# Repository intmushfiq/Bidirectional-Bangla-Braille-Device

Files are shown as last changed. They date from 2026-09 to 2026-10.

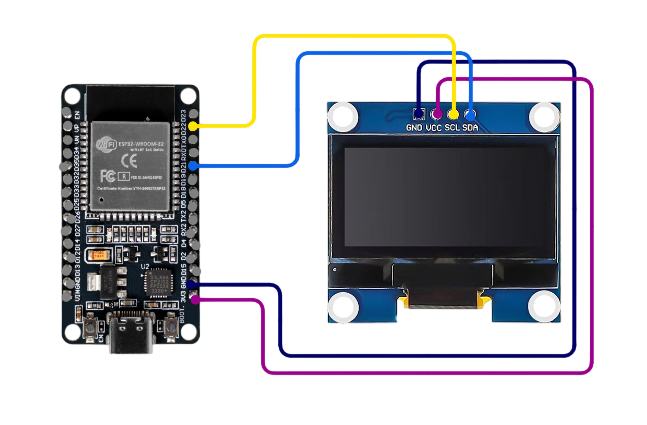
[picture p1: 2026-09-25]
Schematic/OLED_Schematic.png

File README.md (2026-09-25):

# Bidirectional Bangla Braille Translation System

An ESP32-based assistive device that translates **in both directions between six-dot Braille and Bangla text**.

- **WRITE mode (Braille → Bangla):** a blind user types Braille on a six-key keypad. The device shows the Bangla text on an OLED display and speaks each letter through a speaker.
- **READ mode (Bangla → Braille):** a sighted user types Bangla on a web page hosted by the ESP32. The device raises the Braille pattern one letter at a time on a refreshable cell of six solenoids.

EEE 416 (Microprocessor and Embedded Systems Laboratory), Jan 2026 — Section C2, Group 04
Department of EEE, Bangladesh University of Engineering and Technology (BUET)

>  Demo video: *add YouTube link*

---

## Team

| Name | Student ID |
|---|---|
| Mushfiqur Rahman | 2106181 |
| Chayan Paul | 2106182 |
| Shamin Yeaser | 2106183 |
| Kayes Sami Malitha | 2106184 |

---

## Credits and references

- **Audio clips:** letter recordings from [Bengali-Alphabet](https://github.com/lifeparticle/Bengali-Alphabet) by Mahbub Zaman, used under the MIT License. See `audio/LICENSE`.
- **Braille chart:** *World Braille Usage*, 3rd ed., Perkins, ICEB and National Library Service for the Blind and Physically Handicapped, Library of Congress, 2013, "Bangladesh," pp. 9–10.
- **Braille rules:** M. S. Rahman, M. M. Rahman and M. Kaykobad, "Bangla Braille Adaptation," in *Technical Challenges and Design Issues in Bangla Language Processing*, IGI Global, 2013.
- **Libraries:** [BanglaText](https://github.com/mamunul/BanglaText) by Mamunul Mazid · [U8g2](https://github.com/olikraus/u8g2) by Oli Kraus · [DFRobotDFPlayerMini](https://github.com/DFRobot/DFRobotDFPlayerMini) by DFRobot

---

## License

This project is released under the [MIT License](LICENSE). Third-party audio clips and libraries keep their own licenses.

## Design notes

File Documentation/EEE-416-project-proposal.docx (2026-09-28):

Bangladesh University of Engineering and Technology

Department of Electrical and Electronic Engineering

EEE 416 (January 2026)

Microprocessor and Embedded Systems Laboratory

Project Proposal

Section: | C2
Group No: | 04
Student ID(s): | 2106181,2106182,2106183,2106184
Section Teachers: | Tanushri Medha Kundu, Abrar Assaeem Fuad
Project Title: | Design and Implementation of a Bi-directional Bangla Braille Translation Device

# 1 Abstract

This project aims to build a bi-directional Braille learning device that helps visually impaired people read and write in Braille in Bangla. In reading mode, Bangla text is converted into the corresponding Braille pattern, going letter by letter, raising six tactile push-pull solenoids. In writing mode, there is a separate cell in which the user enters a letter using six latching push buttons to spell a word, which is later displayed on an OLED display.

# 2 Background

Braille is the primary means for reading and writing for visually impaired people. However, learning materials in Bangla Braille are scarce and mostly imported, which makes them expensive. Our project aims to build an affordable, low-powered device that allows the user to both read any text file uploaded to the device in real time and also use it as a “Braille Typewriter” to type any word or sentence. This gives learners a self-directed way to practice their reading and writing skills from memory, and can be extended into classrooms and homes where dedicated Braille instructors are not available.

# 3 Complexity Analysis

Our project handles multi levels of complexity which includes-

1. Embedded Hardware Integration: Interfacing the ESP32 with the OLED display, six latching push buttons, speaker module, and Wi-Fi communication.
2. Web-Based File Management: Hosting a web server on the ESP32 to receive text files from a browser and storing them in the LittleFS file system.
3. Braille Translation: Implementing efficient lookup tables to convert Bangla characters into Braille patterns (Reading Mode) and Braille patterns into Bangla characters (Writing Mode).
4. Bangla Text Composition: Processing consonants and vowel signs (কার) to determine the correct character combinations before display.
5. Custom Bangla Rendering: Designing and storing custom bitmap glyphs for Bangla characters since the OLED and U8g2 graphics library do not provide native Bangla font support.
6. Firmware Development: Developing embedded firmware to coordinate hardware control, Braille decoding, file handling, display rendering, and audio feedback in real time.
7. Memory Optimization: Efficiently managing flash memory for firmware, lookup tables, bitmap glyphs, and uploaded text files while minimizing RAM usage during execution.

KPA mapping (the relevant ones from the course outline):

Knowledge Attribute | Application in the Project
K5: Knowledge that supports engineering design in a practice area | The project applies engineering design principles to develop a portable Bangla Braille reading and writing device. The system design includes selecting appropriate hardware components (microcontroller, six tactile Braille buttons, audio output module, and storage), designing separate Reading and Writing modes, implementing Bangla Braille encoding and decoding, and developing a user-friendly interface suitable for visually impaired users.
K6: Knowledge of engineering practice (technology) in the practice areas in the engineering discipline | The project demonstrates engineering practice through the implementation of embedded-system technologies, including microcontroller programming, GPIO interfacing for six tactile button outputs and latching button inputs, file handling for reading Bangla text, Braille pattern generation, Braille input recognition, audio feedback, firmware development (writing the codes in C), and integration of hardware and software into a functional assistive device.
K7: Comprehension of the role of engineering in society and identified issues in engineering practice including ethics, public safety, economic, social, cultural, environmental, and sustainability considerations | The proposed device promotes inclusive education by enabling visually impaired users to read and write in our mother tongue, Bangla. By utilizing low-cost embedded hardware and focusing on the Bangla language, the system improves accessibility, supports independent learning, and demonstrates the role of engineering in developing socially responsible technology.

# 4 Technical Requirements

1.Microcontroller | A programmable microcontroller ( ESP32 ) capable of handling GPIO operations, memory management, and peripheral interfacing.
2. Braille Interface | One cell built of 6 push-pull solenoids for reading mode and another cell with 6 latching buttons for braille writing mode, along with normal push buttons for navigation (read the next letter or take the reading of the next input in writing mode) and mode selection (reading or writing).
4, Speaker | One speaker for audio feedback of the letter just given as input so that the user can confirm if they type correctly.
5. OLED display | One OLED display to show the word typed for others
6. MOSFETs | We need six MOSFETs to drive the output tactile solenoids as they draw large currents, and connecting the solenoids directly to the ESP32 will cause damage.
3. Power Supply | We shall use an adapter that connects to the grid directly to turn on the device and use it as the main power source driving the tactile buttons.

# 5 Proposed Methodology

Reading Mode:

Setup phase (Once per text file)

1. The user connects phone/laptop to the ESP32's WiFi network and opens its IP address in a browser.
2. The ESP32 runs a small web server that serves a simple upload page.
3. The user selects and uploads the Bangla .txt file through that page.
4. The ESP32 receives the raw bytes over WiFi and writes them, unchanged, into a file in its own flash storage using the library LittleFS.h.

Reading loop (runs continuously while displaying)

5. The program opens that saved file and keeps a File object that automatically tracks which byte to read next.

6. On each step, it reads bytes starting at the current position. Since Bengali code points are 3 bytes in UTF-8, it reads 1 first byte to detect a 3-byte sequence, then reads the other 2, and combines all 3 into a single Unicode code point.

7. That code point is looked up in the pre-saved Braille mapping table to get a 6-bit dot pattern.

8. The ESP32 drives the six actuators according to that pattern, raising the correct dots.

9. It waits for the user's "next" button press.

10. On the next press, it loops back to step 6 and reads the next character — continuing from exactly where the file cursor left off, with nothing about the previous character kept in memory.

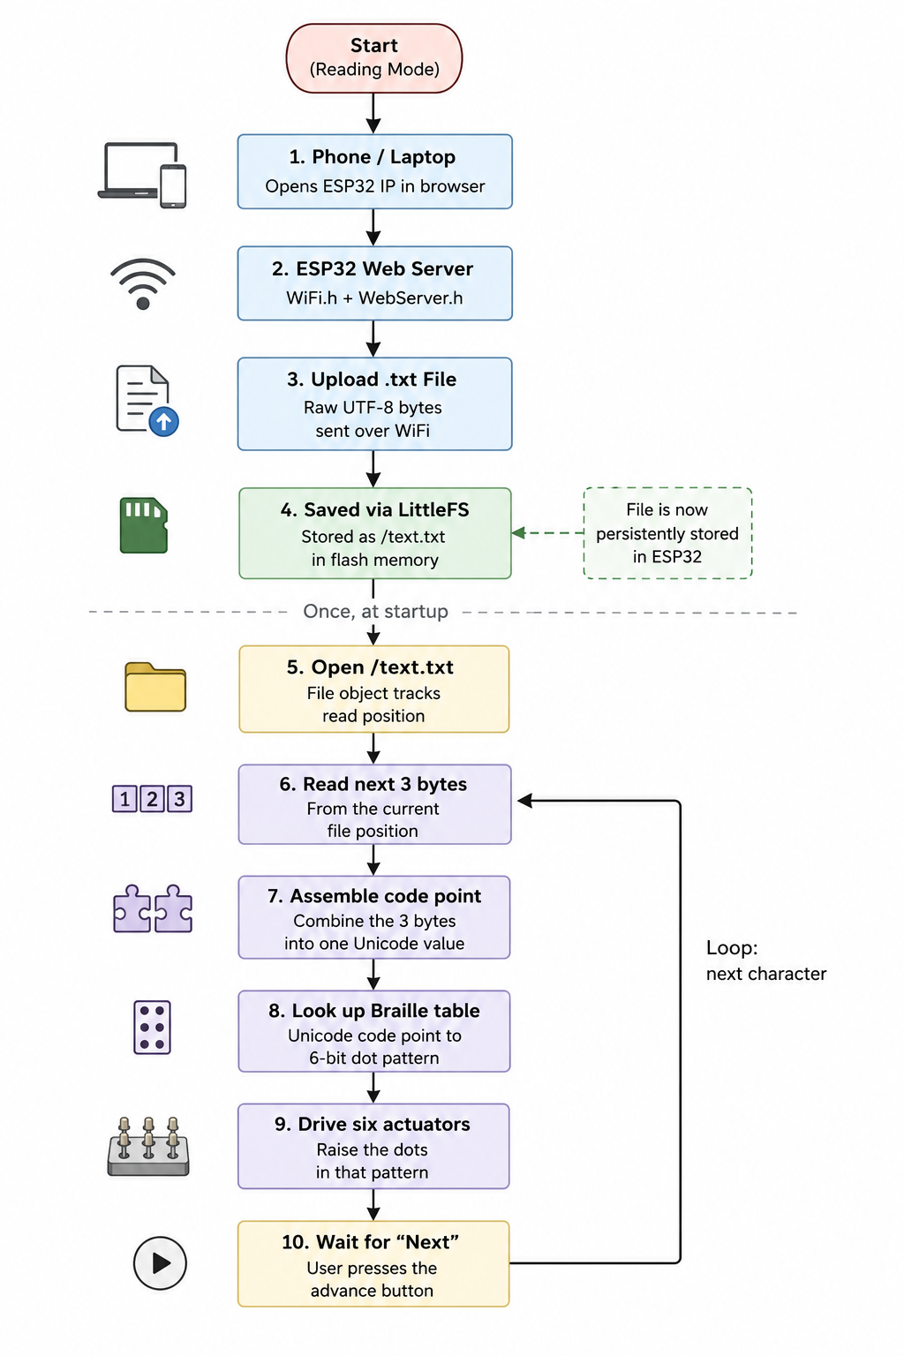
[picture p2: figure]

Fig: Reading Mode

Writing Mode:

There are two main concerns regarding the writing mode,

1. The OLED display does not provide native support for rendering Bangla Unicode characters. Although the U8g2 graphics library manages communication with the OLED and provides drawing functions, it does not include Bangla fonts by default. Therefore, custom bitmap glyphs must be created for each Bangla character (and required character combinations with vowel signs) so that the microcontroller can accurately render the intended text on the display. For simplicity we will map the bitmaps of each individual letter and their vowel attached form in the memory (rather than “building” the “kaar” attached form of that letter from the input) so the whole thing can be used as a look up table.

2. Since Bangla language have “kaar” and the Braille system does not have a separate encoding for “kaar” and assumes that if a vowel appears after consonant it has to be a “kaar” attached to it, we will need to logically implement it using “lookahead buffer” approach before displaying it on OLED. It takes one input and then waits for the next one. If it is a standalone vowel, it directly shows the output but if it is a consonant and the next letter is vowel it combines them to display the text format with “kaar” attached.

The pipeline for the writing mode is as below-

1) The user types a single letter using the 6 latching push buttons.
2) The device waits for the Enter push button
3) It reads the states of the six push buttons and generates the corresponding 6-bit Braille pattern.
4) Searches the Braille lookup table (six bit pattern to direct OLED display glyph Bitmap) to identify the corresponding Bangla character.
5) Determines whether the recognized character is a consonant. If No, retrieve its display glyph from the glyph lookup table and proceed to Step 10.

If Yes, continue to Step 6.

6) Peeks at the next Braille input without permanently processing it.
7) Determines whether the next character is a vowel sign (কার). If Yes, combine the consonant and vowel sign into a composed character (e.g., ক + ি → কি) and retrieve the corresponding glyph from the lookup table. If No, retrieve the glyph corresponding to the consonant alone.
8) Updates the text buffer with the final character or composed character.
9) Generates the corresponding audio output and announces the recognized character through the speaker.
10) Renders the selected glyph on the OLED using the U8g2 graphics library.
11) Repeats the process for the next Braille input until the writing session is complete.

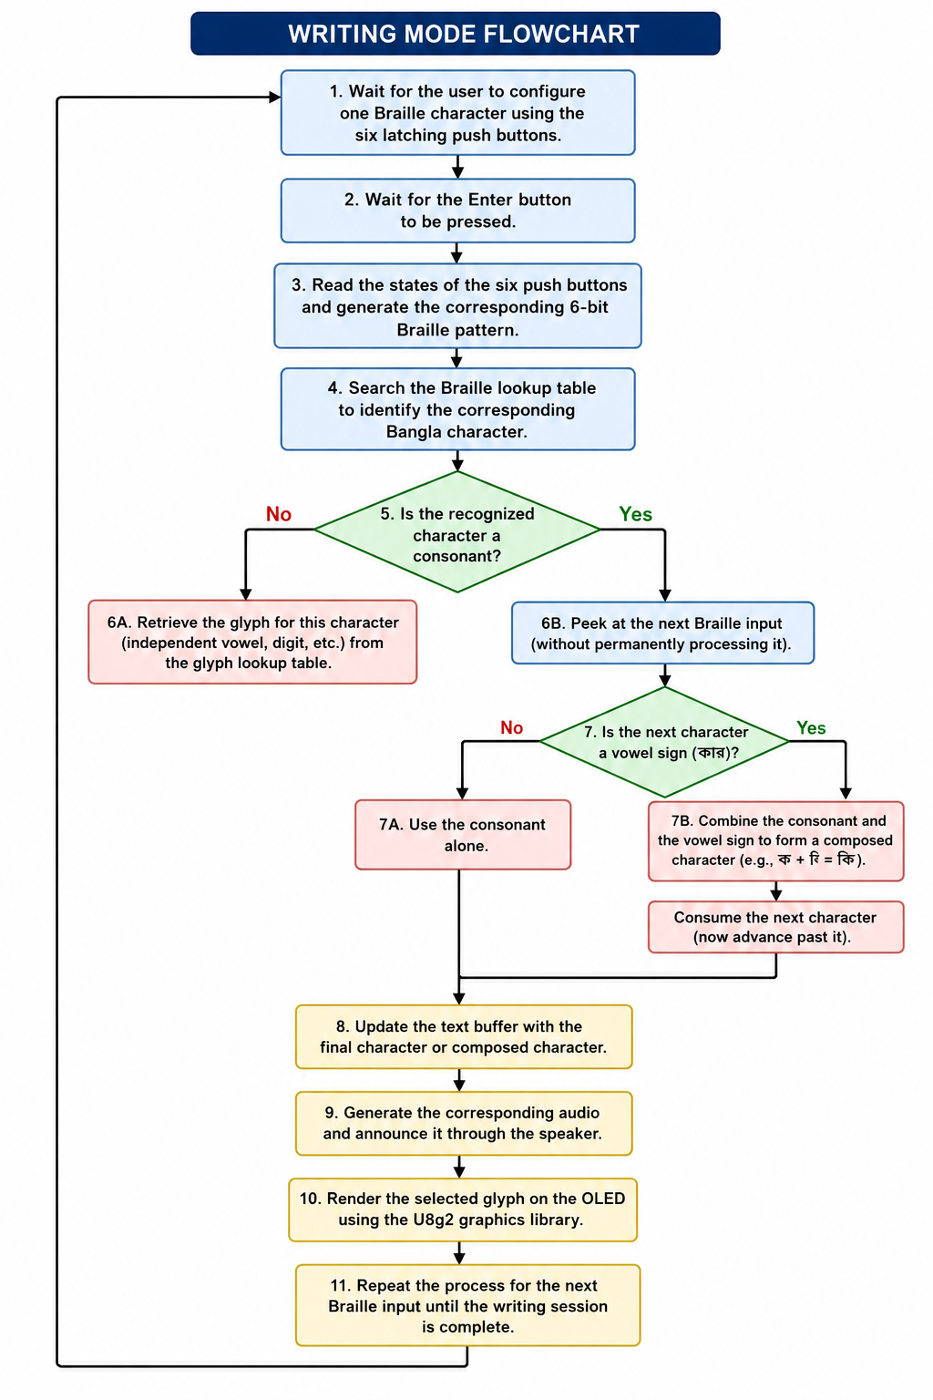
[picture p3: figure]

Fig: Writing mode pipeline

# 6 References

1. https://www.sciencebuddies.org/science-fair-projects/project-ideas/Elec_p109/electricity-electronics/refreshable-braille-display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
2. [1] M. S. Rahman, M. M. Rahman, and M. Kaykobad, "Bangla Braille Adaptation," in Technical Challenges and Design Issues in Bangla Language Processing, M. A. Karim, M. Kaykobad, and M. Murshed, Eds. Hershey, PA, USA: IGI Global, 2013, ch. 2, pp. 17–34.

________________________________________________________________________________________Project Name: Bidirectional braille device EEE 416 (January 2026) C2 Group 04- Project Proposal Page 1

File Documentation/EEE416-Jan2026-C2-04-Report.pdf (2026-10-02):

BA N G L A D E S H UN I V E R S I T Y O F EN G I N E E R I N G A N D TE C H N O L O G Y DE P A R T M E N T O F EL E C T R I C A L A N D EL E C T R O N I C EN G I N E E R I N G

# EEE 416 (January 2026)

## Microprocessor and Embedded Systems Laboratory

# Final Project Report

## Section: C2 Group: 04

# Design and Implementation of a Bidirectional Bangla Braille Translation System

# Course Instructors:

Tanushri Medha Kundu, Lecturer Abrar Assaeem Fuad, Lecturer Signature of Instructor:

# Academic Honesty Statement:

IMPORTANT! Please carefully read and sign the Academic Honesty Statement, below. Type the student
ID and name, and put your signature. You will not receive credit for this project experiment unless this statement is signed in the presence of your lab instructor.
“In signing this statement, We hereby certify that the work on this project is our own and that we have not copied the work of any other students (past or present), and cited all relevant sources while completing this project. We understand that if we fail to honor this agreement, We will each receive a score of ZERO for this project and be subject to failure of this course.”

Signature:
Full Name: Mushfiqur Rahman
Student ID: 2106181

Signature:
Full Name: Chayan Paul
Student ID: 2106182

Signature:
Full Name: Shamin Yeaser
Student ID: 2106183

Signature:
Full Name: Kayes Sami Malitha Student ID: 2106184

1

# Table of Contents

________________________________________________________________________________________ Bidirectional Bangla Braille Translation System EEE 416 (January 2026) C2 Group 04- Final Project Front Matter 2

________________________________________________________________________________________ Bidirectional Bangla Braille Translation System EEE 416 (January 2026) C2 Group 04- Final Project

## 1 Abstract

Braille is the primary reading and writing medium for people who are blind, but very few sighted family members, teachers or classmates can read it, so communication between the two groups breaks down in both directions. Commercial refreshable Braille displays are built around English and cost several hundred US dollars, which places them far beyond the reach of most Bangladeshi learners. This project presents the design and implementation of a low-cost, bidirectional Bangla Braille translation device built around an ESP32 microcontroller. In the WRITE direction, the user types on a six-dot Braille keyboard read through a PCF8575 I²C expander; the firmware decodes the dot pattern into the corresponding Bangla character, renders it on a 128 × 64 OLED display using the BanglaText and U8g2 libraries, and plays the matching pre-recorded clip through a DFPlayer Mini and a 4 Ω speaker. In the READ direction, Bangla text is sent from any phone or computer to a web page hosted on the ESP32’s own Wi-Fi access point; the firmware decodes the UTF-8 stream, applies the Bangla Braille rules for কার signs, conjuncts, ঋ and ৎ, numbers and punctuation, and drives six solenoids that form one refreshable tactile Braille cell, which the reader steps through with NEXT and PREVIOUS buttons. Content and cursor position are preserved when the user toggles between the two modes. The complete prototype was realised on veroboard at a material cost of about BDT 10,840, roughly one-fifth the price of the cheapest commercial refreshable display.

## 2 Introduction

Braille is a six-dot tactile code that gives blind readers direct, independent access to written language. In Bangladesh it is taught in integrated schools and used in examinations, yet almost nobody outside the blind community can read it. The result is a two-way communication gap: a blind student can write a note in Braille that a sighted teacher cannot read, and a sighted parent can write a note in Bangla that a blind child cannot read. Closing that gap requires a device that translates in both directions, not merely a reader or a writer.
Devices that could close part of this gap already exist, but they are not practical here. Refreshable Braille displays such as the HumanWare Brailliant BI 40X or the Orbit Reader 20 are engineered around English contracted Braille and are priced from about US$ 449 upwards [1], [2] — several times the monthly income of a typical Bangladeshi household. None of them implement the Bangla Braille code, which has its own rules for dependent vowels (কার), conjunct clusters (যুার), the special letters ঋ and ৎ, and number and punctuation signs [5], [6].

Figure 1: (Left) Embossed Braille text, the medium blind readers use [3]. (Right) A commercial refreshable Braille display, HumanWare Brailliant BI 40X, priced beyond most Bangladeshi users [4].
The objective of this project is therefore a single, low-cost, self-contained device that performs both conversions: Bangla Braille input to Bangla text with speech output, and Bangla text input to physical, refreshable Braille output. Figure 2 shows the finished prototype and the two directions of translation

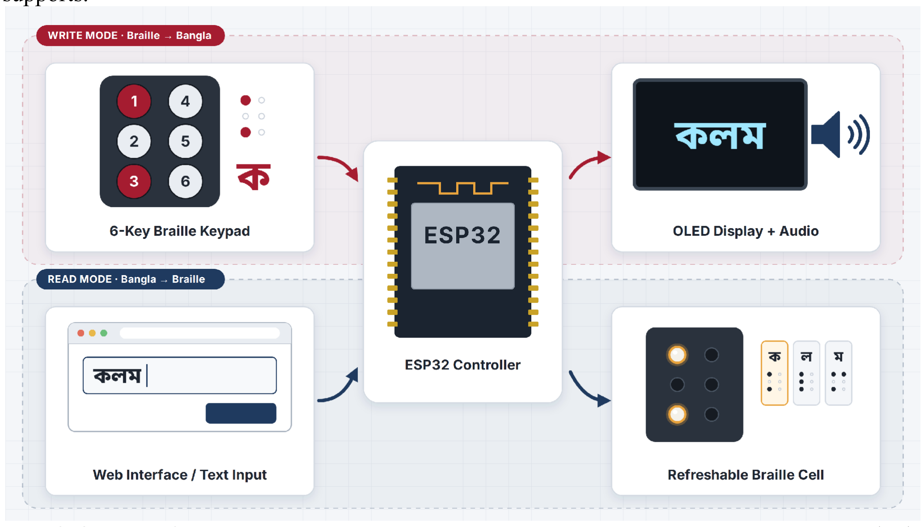
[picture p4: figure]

________________________________________________________________________________________

it supports.

Figure 2: Concept of the bidirectional Bangla Braille communication system: Braille keyboard → Bangl a text and speech, and Bangla text → refreshable tactile Braille.
Why this is a complex engineering problem
The problem satisfies several of the attributes of a complex engineering problem:
- Depth of knowledge required — the solution cannot be reached from one discipline alone. It needs embedded firmware, electromagnetic actuator driving, power electronics, I²C and UART peripheral interfacing, Unicode text processing, web technology and a working knowledge of the Bangla Braille standard.
- Conflicting requirements — tactile output demands high coil current and mechanical force, while portability demands low power and low heat. Low cost conflicts with the number of Braille cells; responsiveness conflicts with the debouncing needed by mechanical latching switches.
- No obvious solution — Bangla Braille is not a one-to-one character mapping. A single Bangla grapheme may occupy one, two or three cells, and one cell (for example dots 2-5-6) means different things inside and outside number mode, so the translation is context dependent and must be resolved by an ordered rule set rather than a lookup table alone.
- Infrequently encountered issues — silent অ, zero-width joiners in যversus র , and the two-cell forms of ঋ and ৎ have no equivalent in English Braille and are not handled by any off-the-shelf library.
- Outside the scope of standards — no Bangladeshi standard covers a single-cell refreshable display, so the cell geometry, the READ/WRITE interaction model and the navigation scheme all had to be defined by the team.
- Diverse groups of stakeholders — blind users, sighted family members and teachers, and Braille instructors all interact with the same device through different modalities (touch, sight and hearing).
- Interdependence — the keyboard, decoder, display, audio player, translator and solenoid driver are separate subsystems, but a change in any one of them (for example the shared I²C bus or the 5 V rail) propagates through the rest.

________________________________________________________________________________________

Alternative solutions considered
Three broad approaches were weighed before the present architecture was adopted:
- A smartphone application with a camera — the phone photographs embossed Braille and reads it aloud, as in the geometric approach of Kamal et al. [7]. This is inexpensive but works in one direction only, needs good lighting and a steady hand, and gives the blind user no tactile output at all.
- A full multi-cell refreshable display — 20 or 40 piezo cells, as used commercially [2]. This gives the best reading experience but the piezo bimorph stack alone costs more than the entire budget of this project.
- A single refreshable cell with solenoid actuation plus audio and visual feedback — the option chosen here. One cell keeps the cost and the power budget within reach, the loss in reading speed is compensated by the spoken feedback, and the same microcontroller can host both translation directions and the web interface.

## 3 Design

## 3.1 Problem Formulation (PO(b))

### 3.1.1 Identification of Scope

The device was scoped around the following functions, all of which are implemented in the delivered prototype:
- Designing a six-dot physical Braille keyboard with latching pushbuttons.
- Converting an entered Braille pattern into the corresponding Bangla character.
- Supporting Bangla vowels, consonants, কার signs, conjunct clusters, numbers, punctuation and the special Braille sequences for ঋ and ৎ.
- Displaying the generated Bangla text on an OLED and providing spoken audio feedback for every entry.
- Receiving Bangla text from any phone or computer through a web page hosted by the ESP32 itself.
- Converting that Bangla text into six-dot Braille patterns and producing physical Braille output through six solenoids.
- Allowing the reader to navigate the translated message cell by cell with NEXT and PREVIOUS controls, and to switch between READ and WRITE modes without losing the current content or position.
Deliberately left outside the scope are: grade-2 (contracted) Braille, languages other than Bangla, synthesised text-to-speech, multi-cell displays and an enclosure certified for commercial sale. These are revisited in Section 9.

### 3.1.2 Literature Review

Existing work was surveyed along two lines: the definition of the Bangla Braille code itself, and hardware that reads or writes Braille. Table 1 summarises the sources that shaped this design and the gap each one leaves.

________________________________________________________________________________________

Existing work | What it does | Gap for our problem
Rahman, Rahman & Kaykobad — Bangla Braille Adaptation [5] | Defines the Bangla Braille code: letters, কার, conjunct and number rules | A standard only — no device
World Braille Usage, 3rd ed. — Bangladesh chart [6] | Official Bangla Braille cell for every letter, কার, sign, digit and punctuation mark | Reference chart only — no device
Kamal et al. — Braille-to-text for Bengali [7] | Scanned embossed Braille → Bangla text (97.25 % accuracy) | One direction; needs a scanner; no tactile output
Tabassum et al. — low-cost mechanical Braille display [8] | Refreshable tactile display hardware for Bangladeshi students | Output only; no Braille typing or text entry
Orbit Reader 20 (commercial) [2] | 20-cell refreshable display with Bluetooth / USB | US$ 449; not built around Bangla rules
Arduino refreshable Braille cell This project project [9] | Single do-it-yourself cell driven by a Braille ⇄ Bangla in one device, with OLED, microcontroller | English letters, one direction only
| audio feedback and web input | Handles কার, silent অ, conjuncts, ঋ / ৎ and numbers

Table 1: Survey of existing work and the gap each leaves for this project.

The survey shows a clear vacancy. The linguistic rules are fully documented [5], [6] and low-cost tactile hardware has been demonstrated [8], [9], but no reported system combines the two directions for Bangla in a single affordable unit. That vacancy defines the problem addressed here.

### 3.1.3 Formulation of Problem

The overall task separates into two conversion problems that share the same hardware and the same microcontroller, plus a state-management problem that links them.
Problem 1 — Braille to Bangla (WRITE mode).
W orkflow: six Braille keys → Braille pattern → Bangla character →O LED + audio. Formally, the firmware must realise a mapping
f : {0,1}⁶ × S → Σ × S (3.1) where {0,1}⁶ is the set of 64 possible dot patterns of one cell, Σ is the Bangla character set and S is the decoder state (pending conjunct prefix, pending dot-5 prefix, number mode, last emitted character). The state argument is unavoidable: the same pattern produces different output depending on what preceded it.
Problem 2 — Bangla to Braille (READ mode).
W orkflow: Bangla text → UT F-8 processing → Braille pattern → solenoid output. T he firmware must realise the inverse mapping
g : Σ* → ({0,1}⁶)* | (3.2)
which is not injective in either direction and is not length preserving: one Bangla grapheme may expand to one, two or three cells (a conjunct cluster expands to a prefix cell plus one cell per consonant), and conversely a prefix cell carries no character of its own.
Mode switching.
A single latching MODE button toggles the two problems. The requirement is that the text buffer of WRITE mode and the cell index of READ mode both survive the toggle, so that a user can feel a cell, switch to WRITE to answer, and switch back without losing position.

### 3.1.4 Analysis

Each major design decision was taken by comparing the realistic alternatives against the project constraints: a material budget under BDT 8,000, operation from a single 5 V rail, no dependence on an internet connection or an external router, and full coverage of the Bangla Braille code. Table 2 records the comparison.

________________________________________________________________________________________

Decision | Options considered | Chosen option and reason
Tactile actuator | Piezoelectric cell, micro servo, solenoid | Solenoid — low cost, fast, and driven by a simple on/off signal; piezo cells cost more than the whole budget and servos are bulky and noisy
Solenoid driver | Direct GPIO, bipolar transistor, logic-level MOSFET | IRLB8721 MOSFET — fully enhanced at 3.3 V gate drive with very low conduction loss; a flyback diode protects it [10]
Button inputs | Nine direct GPIO pins, I/O expander | PCF8575 — all nine buttons on the two-wire I²C bus already used by the OLED, freeing ESP32 pins for the six solenoid channels [10]
Audio feedback | Cloud text-to-speech, pre-recorded clips | DFPlayer Mini with microSD — instant playback and fully offline operation [10]
Bangla text input | File upload to flash, live web form | ESP32-hosted web page — usable from any phone or PC with no app and no router
Bangla display | Hand-made bitmaps, font library | BanglaText with U8g2 — shapes কার signs and conjuncts automatically [11], [12]
Table 2: Design decisions, alternatives considered and the reason for each choice.

## 3.2 Design Method (PO(a))

This section sets out how knowledge of mathematics, electronics and computer engineering was applied to realise the two mappings of equations (3.1) and (3.2). It moves from the hardware architecture, through the input, display and audio subsystems, to the power electronics, and then to the two translation algorithms.

### 3.2.1 System Architecture and Component Selection

The system is built around a 30-pin ESP32 DevKit, which carries all the logic, hosts the Wi-Fi access point and runs the web server. Table 3 lists the components and the role of each in the system.
Component | Role in the system
ESP32 DevKit (30-pin) | All logic, Wi-Fi access point and web server
SH1106 128 × 64 OLED display (I²C) | Shows Bangla text in both modes
PCF8575 I/O expander | Reads the six dot keys plus ENTER/NEXT, BACKSPACE/PREVIOUS and MODE
DFPlayer Mini + microSD + speaker | Plays 104 pre-recorded Bangla clips
5 V 1 A push-pull solenoids × 6 | Form one refreshable tactile Braille cell
IRLB8721 MOSFET + 1N5819 diode × 6 | Logic-level switching and flyback protection for each coil
LiPo battery and buck converter | 5 V supply for the solenoids and the DFPlayer
Table 3: Hardware components and their role in the system.

Two serial buses carry all peripheral traffic. The OLED (address 0x3C) and the PCF8575 (address 0x20) share one I²C bus on GPIO21 (SDA) and GPIO22 (SCL); the DFPlayer Mini uses a UART on GPIO17 (TX) and GPIO16 (RX). The six solenoid channels take GPIO25, 33, 32, 14, 27 and 26. Sharing the I²C bus is what makes six independent solenoid outputs possible on a 30-pin board.

### 3.2.2 Wi-Fi Access Point and Web Server Hosting

The ESP32 creates its own Wi-Fi access point, so no external router and no internet connection is required. The network is named Braille_Bangla with the password 123456789, and once a phone or laptop joins it the device is reached at 192.168.4.1. The HTML of the page is stored in the firmware itself, in the header file WebPage.h; the root route “/” serves that page and the route “/send” receives the text when the user presses the send button.

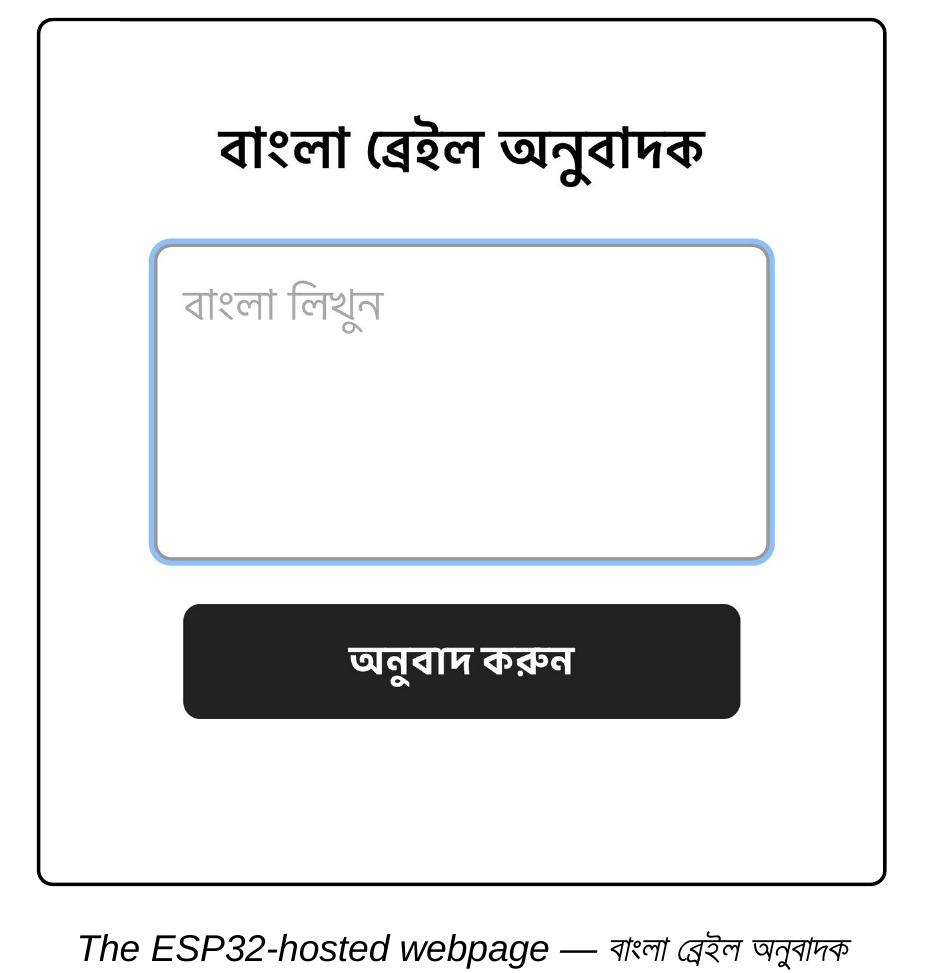
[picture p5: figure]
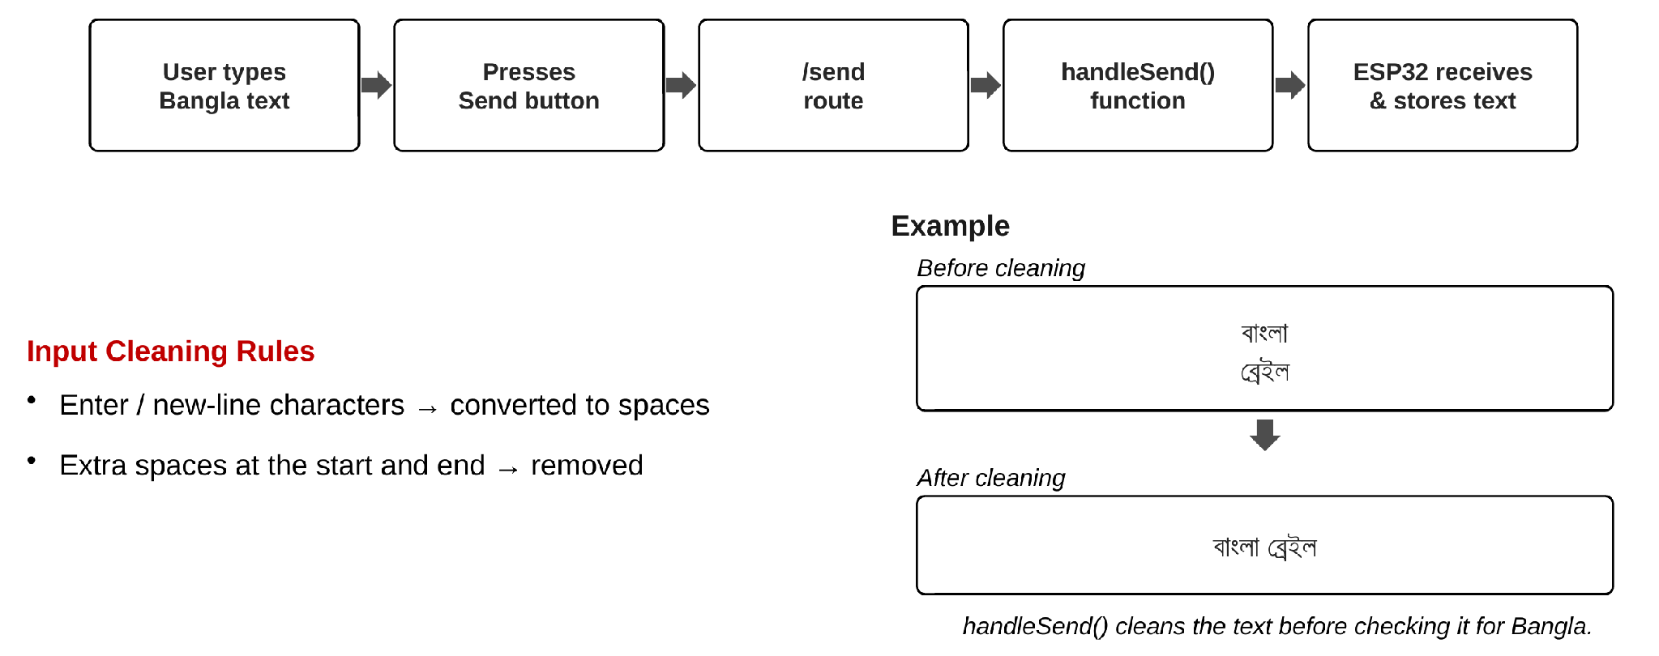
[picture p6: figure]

________________________________________________________________________________________

Figure 3: The ESP32-hosted web page বাংলা েইল অনুবাদক, through which a sighted user types Bangla text.

### 3.2.3 Receiving and Cleaning the Input

The text posted to “/send” is handled by handleSend(). Before the text is used it is cleaned: carriage-return and line-feed characters are converted into single spaces, and leading and trailing spaces are stripped. This step was added after an early version misbehaved when raw Enter characters reached the translator, because a newline inside the buffer terminated number mode in the wrong place and shifted every subsequent cell.

Figure 4: Path taken by the text from the browser to the ESP32, and the effect of the cleaning rules.

### 3.2.4 Input Text Validation

The cleaned string is then validated. Every code point is tested against the Bengali Unicode block, U+0980 to U+09FF, together with a short list of additionally permitted characters (space, the Bangla দাঁিড় and the punctuation marks that have Braille cells). If the string contains characters outside that set the translation is abandoned: the OLED shows দয়া কের বাংলা িলখুন, a warning clip is played, and all six solenoids are de-energised so that the reader is never left with a stale cell under the fingertip.

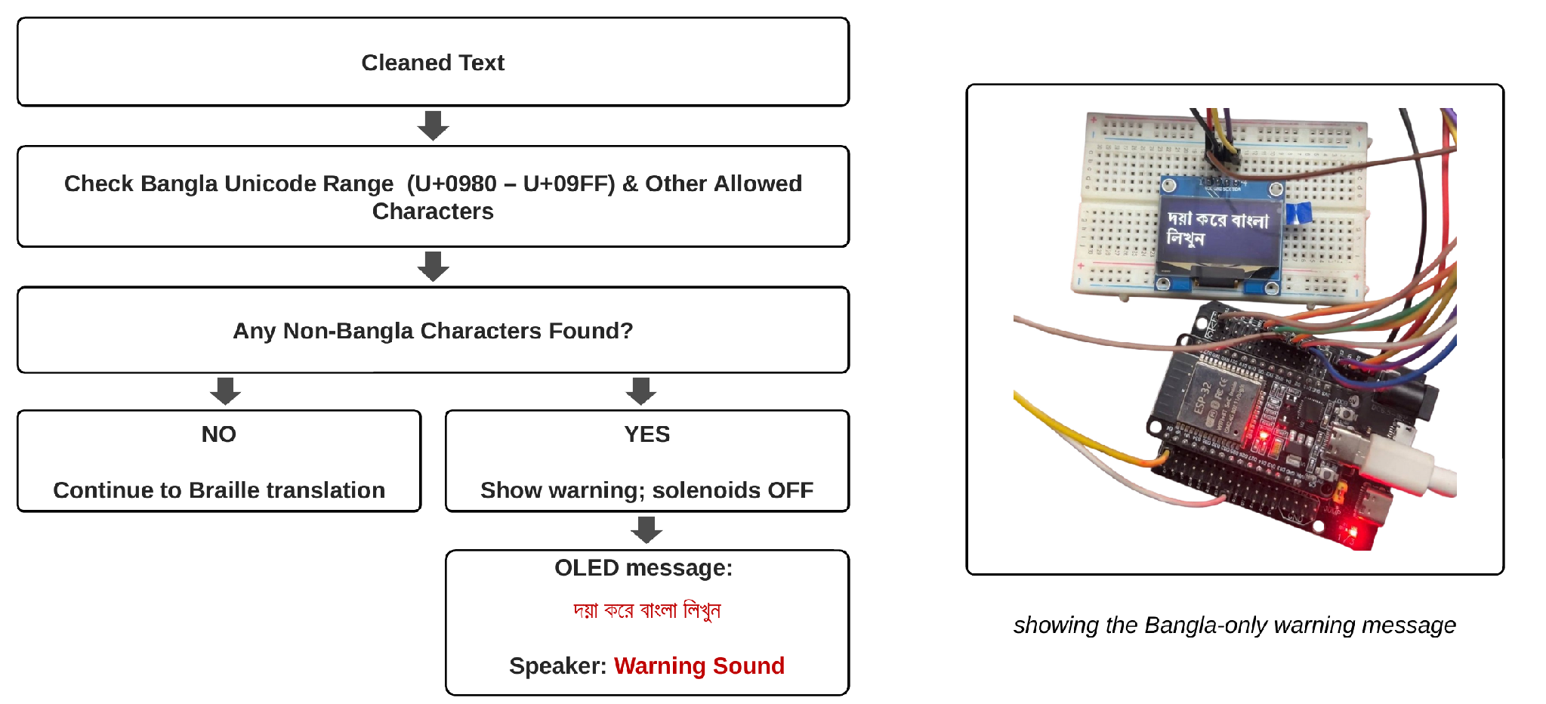
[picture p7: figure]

________________________________________________________________________________________

Figure 5: Validation of the received text and the warning state shown on the OLED when non-Bangla input is detected.

### 3.2.5 Rendering Bangla Text on the OLED

Bangla cannot be drawn by a simple character-to-bitmap loop, because কার signs attach to the left, right, above or below the consonant they modify and conjuncts change glyph shape entirely. The BanglaText library by Mamunul Mazid [11] is therefore used on top of the U8g2 monochrome graphics library [12]. BanglaText carries a font header file that stores the Bangla glyphs together with their pixel mapping and performs the reordering and shaping; U8g2 pushes the resulting bitmap to the SH1106 panel over I²C.

Figure 6: Chain from Bangla text to OLED pixels through the BanglaText font library [11] and U8g2 [12].

### 3.2.6 Audio Subsystem

Audio feedback is produced by a DFPlayer Mini reading MP3 files from a microSD card [13] and driving a 4 Ω, 3 W speaker directly from its on-board amplifier. The module is commanded over UART, so a playback request costs the ESP32 only a short serial frame and no processing time. There are 104 clips on the card in total: one for each Bangla letter, কার sign and digit, and additional clips for space, new line, backspace, mode change and invalid input.

Figure 7: DFPlayer Mini module and speaker used for the spoken feedback [13].

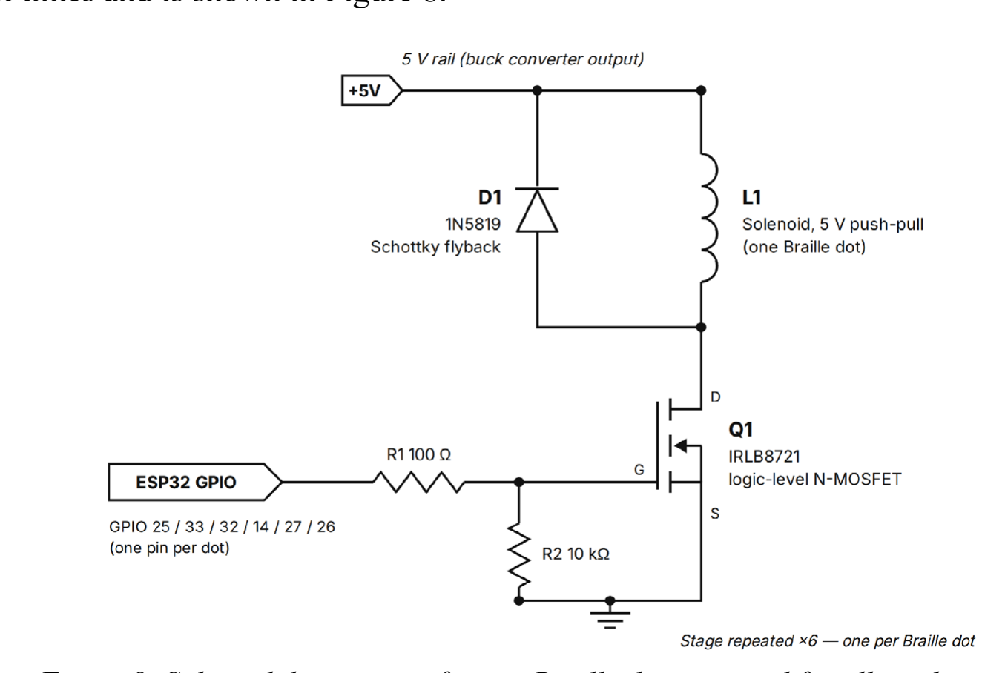
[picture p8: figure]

________________________________________________________________________________________

### 3.2.7 Audio Feedback Workflow

In WRITE mode every confirmed entry is spoken back immediately, which is what allows a blind user to verify a keystroke without sighted help. The sequence is:
- The user latches a dot pattern on the six keys and presses ENTER.
- The pattern is decoded to a Bangla character through the state machine of equation (3.1).
- The ESP32 sends the track number associated with that character to the DFPlayer over UART.
- The DFPlayer reads the corresponding MP3 file from the microSD card — for example the clip for ক — and plays it on the speaker.
Because the mapping from character to track number is a fixed table, no speech synthesis is needed and the response is effectively instantaneous.

### 3.2.8 Solenoid Driver Stage

Each of the six dots is a 5 V push-pull solenoid drawing about 1 A when energised, far beyond the 40 mA that an ESP32 pin can source, so every dot has its own low-side switch. The stage is repeated identically six times and is shown in Figure 8.

Figure 8: Solenoid driver stage for one Braille dot, repeated for all six dots. The switching components were selected so that every rating is met with a wide margin, as set out in Table 4.
Component | Parameter | Device rating | Value in this design
IRLB8721 MOSFET | Maximum drain–source voltage V_DS | 30 V | 5 V rail, clamped to about 5.4 V at turn-off
IRLB8721 MOSFET | Maximum continuous drain current I_D | 62 A | 1 A per coil
IRLB8721 MOSFET | Gate threshold voltage V_GS(th) | 2.5 V | 3.3 V gate drive from the ESP32 GPIO
1N5819 Schottky diode | Reverse standoff voltage | 40 V | 5 V across the coil
1N5819 Schottky diode | Average forward current | 1 A | 1 A freewheeling coil current
Push-pull solenoid | Supply voltage and coil current | 5 V, 1 A | 5 V rail, about 1 A when energised
Table 4: Ratings of the switching components in one driver channel and the values they actually see.

The 30 V drain–source rating gives roughly a six-fold margin over the 5 V rail, and the 62 A drain-current rating is more than sixty times the 1 A coil current, so the MOSFET is operating far inside its safe area and no derating for temperature rise is necessary. The 2.5 V gate threshold is the figure that

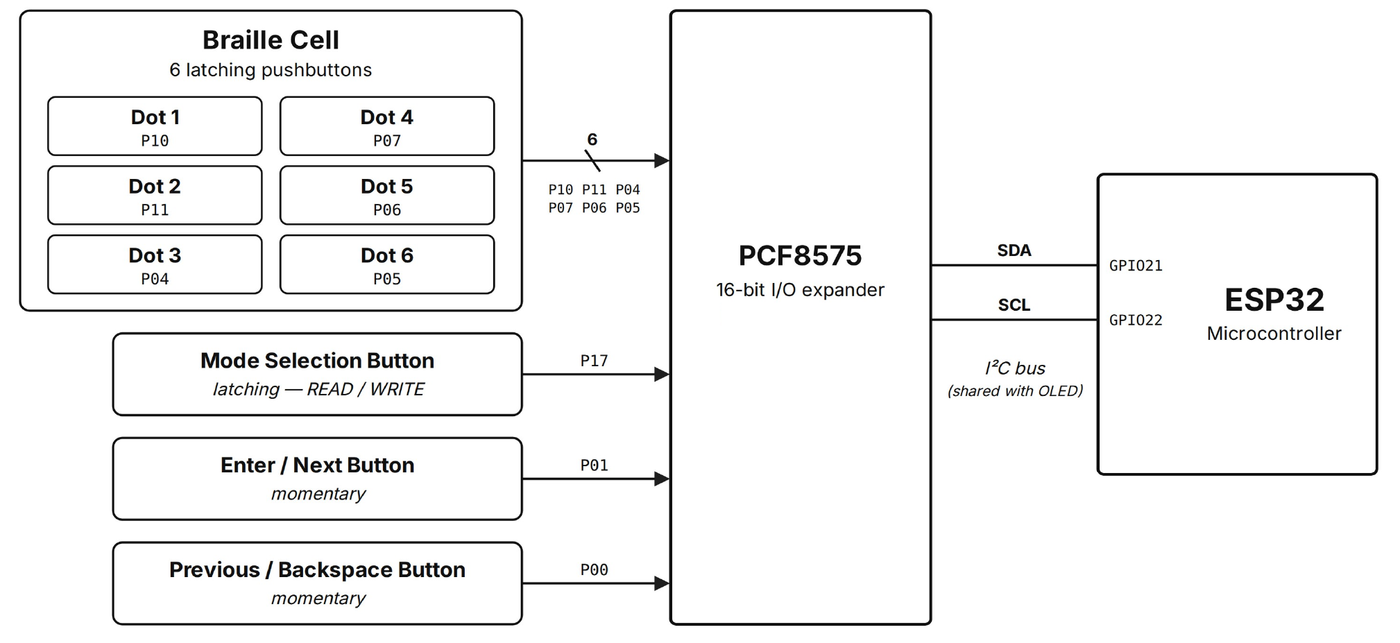
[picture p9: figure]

________________________________________________________________________________________ makes the part usable here at all: it is below the 3.3 V that an ESP32 pin can deliver, which is why a logic-level device was specified rather than a standard MOSFET needing 10 V of gate drive. On the diode side, the 40 V reverse rating covers the clamped spike with a very large margin, while the 1 A forward rating matches the full coil current it must carry during the freewheel interval.
MOSFET switch.
The IRLB8721 is a logic-level N-channel MOSFET: it is fully enhanced by the 3.3 V that an ESP32 GPIO delivers, with a typical on-state resistance of about 16 mΩ. The conduction loss in each device is therefore
P_cond = I_D² · R_DS(on) = (1 A)² × 0.016 Ω ≈ 16 mW | (3.3)
which needs no heatsink. A 100 Ω series gate resistor limits the peak gate-charging current to I_G(peak) = V_GS / R₁ = 3.3 V / 100 Ω = 33 mA (3.4) which is comfortably inside the ESP32 pin rating, and a 10 kΩ pull-down holds the gate at 0 V while the ESP32 boots so that no dot is raised spuriously at power-up. The steady-state current wasted in that pull-down is only 3.3 V / 10 kΩ = 0.33 mA per channel.
Flyback protection.
A solenoid is an inductive load. When the MOSFET turns off, the collapsing field generates
v_L = L · di/dt | (3.5)
and because di/dt is very large at turn-off this spike would exceed the drain-source rating of the MOSFET. A 1N5819 Schottky diode connected across the coil provides a freewheeling path, clamping the drain to roughly V₊ + 0.4 V. The Schottky type is chosen over an ordinary silicon diode for its low forward drop and fast recovery, so that the stored energy ½·L·I² decays quickly enough for the cell to refresh at a usable rate.

### 3.2.9 Pushbutton Input Subsystem

Nine buttons are needed: six latching switches for dots 1 to 6, one latching switch for MODE, and two momentary switches whose function depends on the mode — ENTER/NEXT and BACKSPACE/PREVIOUS. Wiring all nine to the ESP32 directly would consume the pins reserved for the solenoids, so they are read instead through a PCF8575 16-bit I/O expander sitting on the same I²C bus as the display. The expander has internal pull-ups, so each switch simply grounds its port pin, and the whole keyboard is read in a single two-byte I²C transaction.

Figure 9: Pushbutton input subsystem: nine switches read through the PCF8575 expander on the shared I²C bus.
Latching switches were chosen for the six dots deliberately. A blind user can set several dots, feel the mechanical state of the keys to confirm the pattern, and only then press ENTER — an affordance that momentary buttons would not give. Their state is polled and software-debounced; the pattern is only committed on the ENTER edge.

________________________________________________________________________________________

### 3.2.10 Complete Wiring of the Device

Figure 10 brings the subsystems together. The ESP32 sits at the centre; the OLED and PCF8575 hang off the I²C bus on the left, the DFPlayer on the UART below, and the six MOSFET drivers and solenoids on the right. The solenoid rail and the ESP32 share a common ground, and the 5 V for the coils comes from the buck converter rather than from the ESP32 regulator, so that a coil inrush cannot brown out the microcontroller.

Figure 10: Complete wiring of the device, showing the two serial buses, the six solenoid channels and the power distribution.

### 3.2.11 Power Budget and Supply Design

The supply was sized for the worst case in which all six dots are raised simultaneously, the Wi-Fi access point is transmitting and a clip is playing. Each coil is a 5 V, 1 A device, so its winding resistance is
R_coil = V / I = 5 V / 1 A = 5 Ω, P_coil = V · I = 5 W | (3.6)
and the total demand is the sum in Table 5.
Load | Current (approximate)
6 solenoids × 1 A (worst case: all dots raised) | 6.0 A
ESP32 with Wi-Fi access point (peaks) | 0.5 A
DFPlayer Mini + 3 W speaker | 0.6 A
OLED + PCF8575 | < 0.05 A
Total | ≈ 7.2 A → 36 W
Table 5: Worst-case power budget of the complete device.

Currents other than the solenoid current are typical datasheet-level figures; the purpose of the calculation is to fix the supply rating rather than to predict consumption precisely. A LiPo pack with a buck converter rated at 90 W was used, leaving a margin of well over two to one. In practice the average draw is far lower, because a Braille cell is only energised while the reader's finger is on it and a typical pattern raises two or three dots rather than six.

### 3.2.12 Braille Input Rules (Braille → Bangla)

A Braille cell has six dots, so there are 2⁶ = 64 distinguishable patterns, 63 of them non-blank. Bangla has far more graphemes than that, which is precisely why the code is context dependent and why the state argument appears in equation (3.1). Six cases had to be handled explicitly [5], [6]; each is described below with the corresponding cell diagrams.

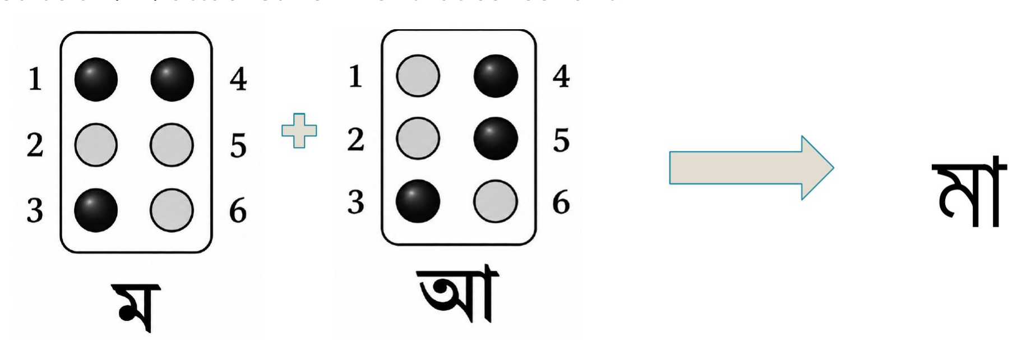
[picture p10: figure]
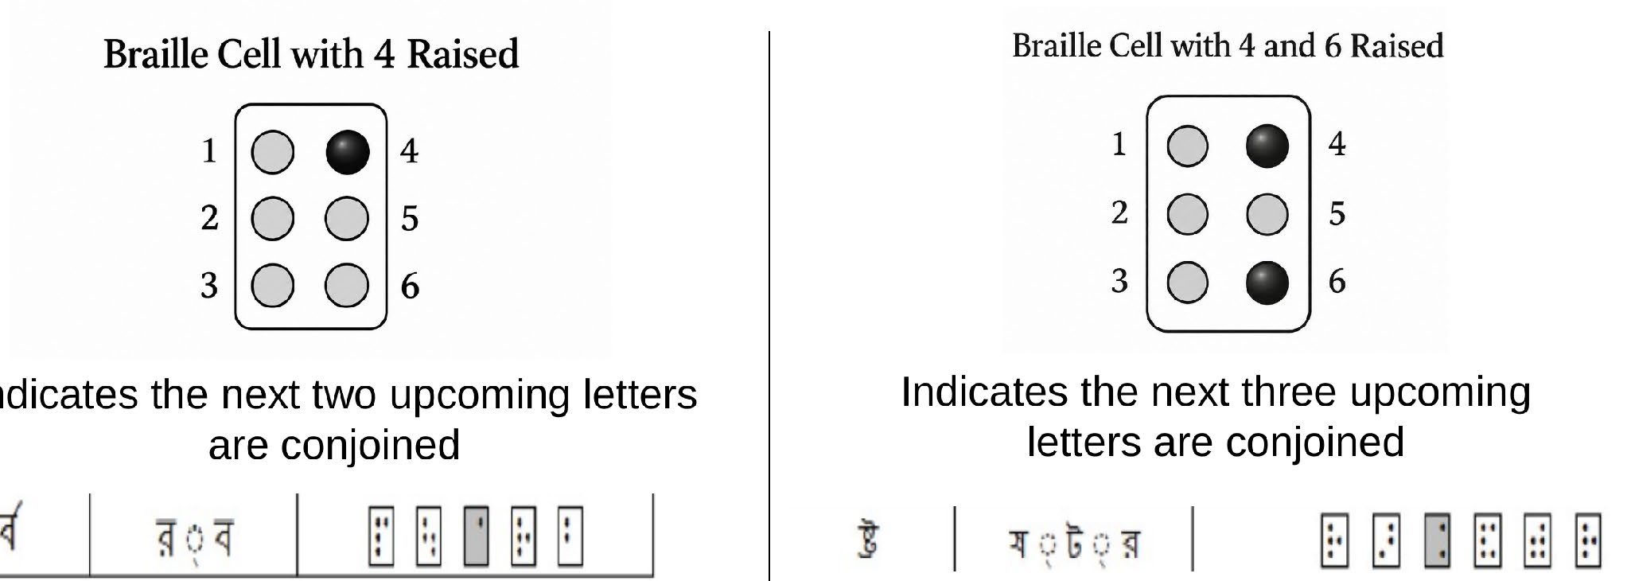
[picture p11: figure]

________________________________________________________________________________________

Case 1 — Dependent vowels (কার).
In Braille an independent vowel (আ, ই) and its dependent form (◌া, ি◌) share exactly the same cell. The decoder therefore decides from context: if the vowel pattern arrives directly after a consonant, it is rendered as a কার-attached form of that consonant.

Figure 11: Case 1 — a consonant cell followed by a vowel cell produces the কার-attached form (ম + আ → মা).
Case 2 — Independent vowels (রবণ ).
The same pattern must stay independent when it begins a word, and also when it follows a consonant that has been explicitly closed with the inherent অ sound. The second rule is what distinguishes বই from িব and is handled by tracking whether an explicit অ cell was entered.

Figure 12: Case 2 — a vowel starting a word stays independent (আ + ম → আম); an explicit অ between the consonant and the vowel keeps বই from collapsing into িব. Case 3 — Conjunct letters (যুার).
Bangla Braille does not mark a conjunct with a হস after the fact; it announces one in advance with a prefix cell. Dot 4 alone signals that the next two letters are joined, and dots 4 and 6 together signal that the next three are joined. The decoder therefore latches the prefix, collects the announced number of consonants and only then emits the cluster with the hasanta characters inserted.

Figure 13: Case 3 — the conjunct prefix cells: dot 4 for a two-letter cluster and dots 4-6 for a three-letter cluster.

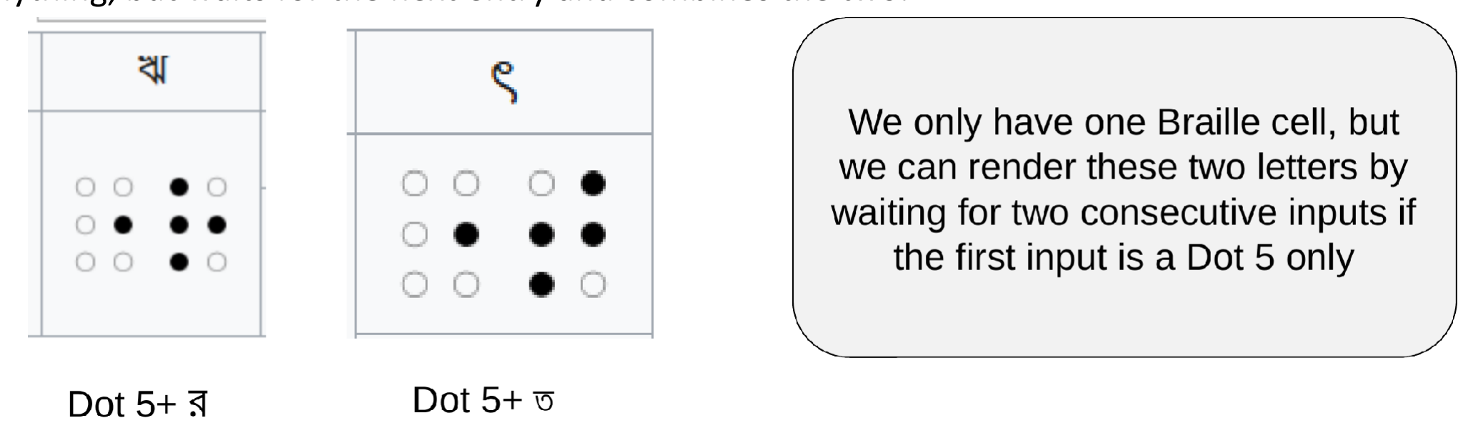
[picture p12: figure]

________________________________________________________________________________________

Case 4 — The special characters ঋ and ৎ.
These two letters occupy two consecutive cells, but they follow a regular pattern: dot 5 followed by র gives ঋ, and dot 5 followed by ত gives ৎ. With only one physical cell available, the decoder emulates the two-cell sequence in time: when the entered pattern is dot 5 alone it does not emit anything, but waits for the next entry and combines the two.

Figure 14: Case 4 — the two-cell sequences for ঋ and ৎ, emulated on a single cell by waiting for the entry that follows a lone dot 5. Case 5 — Conjuncts with র (যand র ).
Both forms begin with the dot-4 conjunct prefix. Pressing dot 4 once joins র and য with a hasanta and yields য, as in কায . Pressing dot 4 twice inserts a zero-width joiner before the hasanta and yields র , as in র াব. The two strings differ by a single invisible code point, U+200D, and would be indistinguishable on screen without this rule.

Figure 15: Case 5 — one dot-4 prefix gives the ordinary conjunct য; two dot-4 prefixes insert a zero-width joiner and give র .
Case 6 — Numbers and punctuation.
A number begins with the number sign, dots 4-5; every cell after it is read as a digit until a space or a new line ends number mode. Punctuation marks have cells of their own. The interesting conflict is dots 2-5-6, which means দাঁিড় (।) in running text but a decimal point inside a number: the sequence 4-5, 1-4, 2-5-6, 1 therefore reads ৩.১, whereas a space before the 2-5-6 cell ends number mode and gives ১। instead.

Figure 16: Case 6 — the number sign and digit cells, the punctuation cells, and the context-dependent meaning of dots 2-5-6.

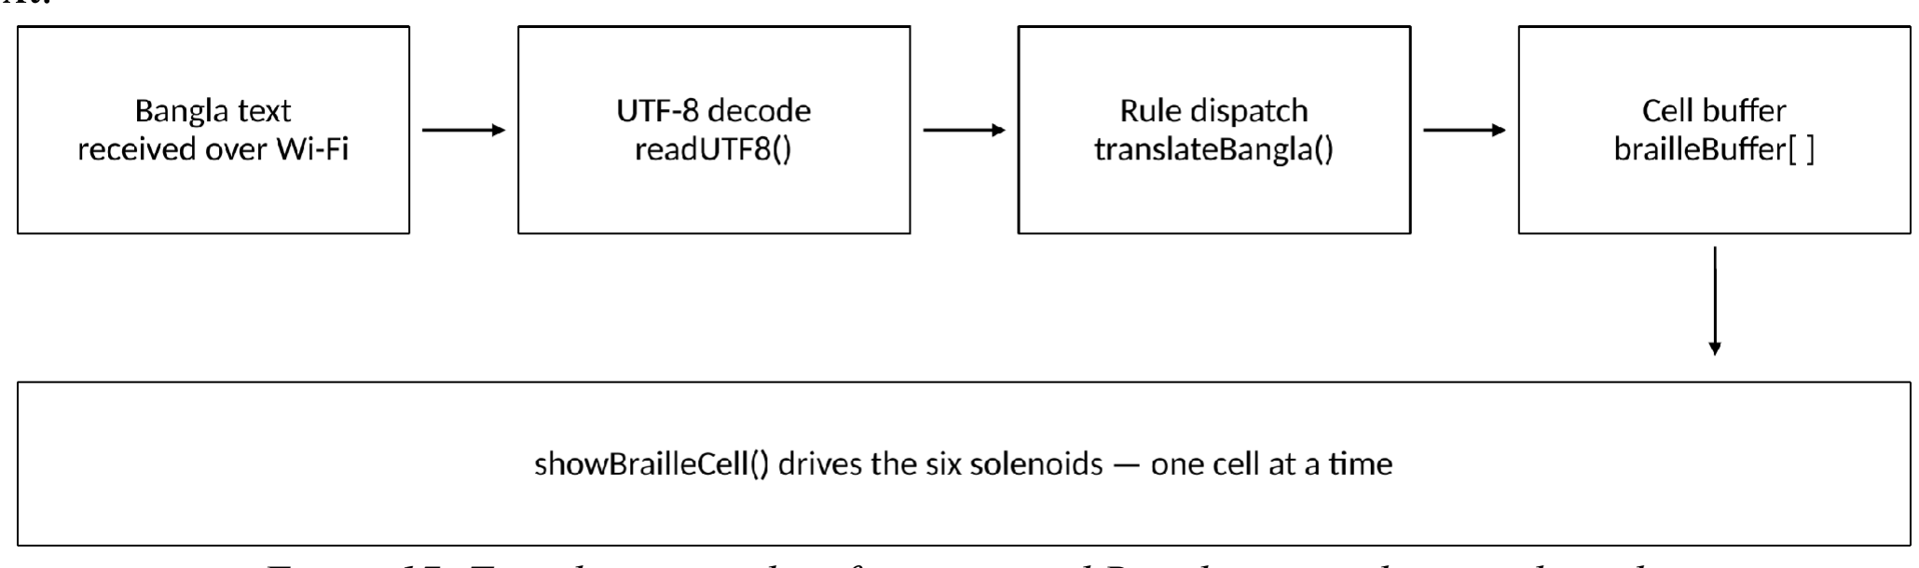
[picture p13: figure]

________________________________________________________________________________________

### 3.2.13 Braille Output Pipeline (Bangla → Braille)

The reverse mapping of equation (3.2) is implemented as a four-stage pipeline that runs once, when a message arrives. Afterwards the NEXT and PREVIOUS buttons only move an index into the translated buffer; nothing is re-translated, so navigation is instantaneous and cannot drift out of step with the text.

Figure 17: Translation pipeline from received Bangla text to the six solenoids.
Step 1 — Decoding the Bangla text.
Bangla code points lie in U+0980–U+09FF and are therefore three bytes each in UTF-8. The helper readUTF8() reconstructs the code point from the three bytes as
cp = ((b₀ & 0x0F) << 12) | ((b₁ & 0x3F) << 6) | (b₂ & 0x3F) | (3.7)
For the bytes E0 A6 95 this gives 0x0995, which is ক. The decoded code point is then matched against the Braille lookup table.

Figure 18: Step 1 — three UTF-8 bytes are reassembled into one Bangla code point.
Step 2 — Storing a Braille cell.
Each cell is stored as a single byte in brailleBuffer[ ], with bit 0 representing dot 1 up to bit 5 representing dot 6. The helper appendPattern() converts a human-readable dot list into that mask:
mask = Σᵢ₌₀ 2^(dᵢ − 1) | (3.8)
so appendPattern(1345), meaning dots 1, 3, 4 and 5, produces 1 + 4 + 8 + 16 = 29 = 0b00011101, the cell for ন. Because the mask is a set of bits, the order in which the digits are written does not matter. The buffer holds 512 cells, that is 512 bytes, which is ample for any message a user will type into the web form.

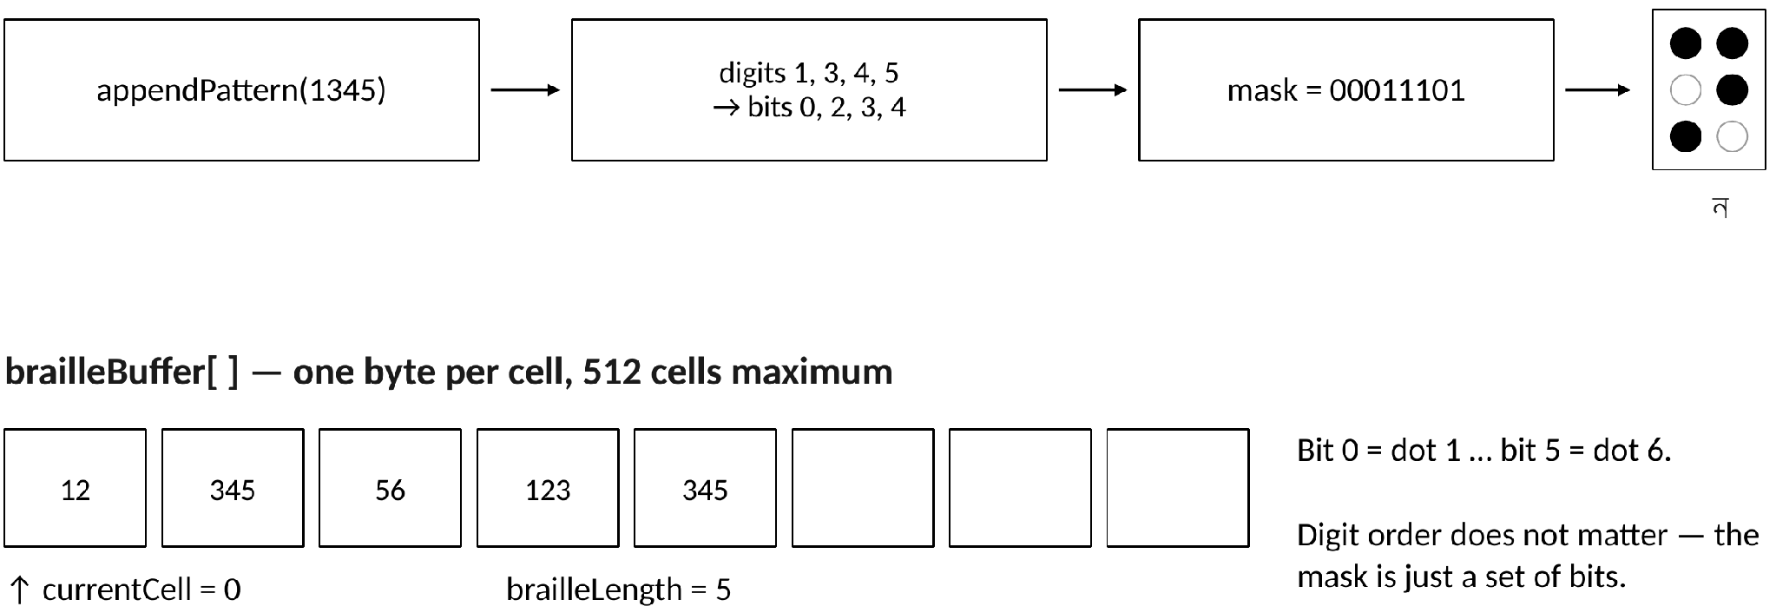
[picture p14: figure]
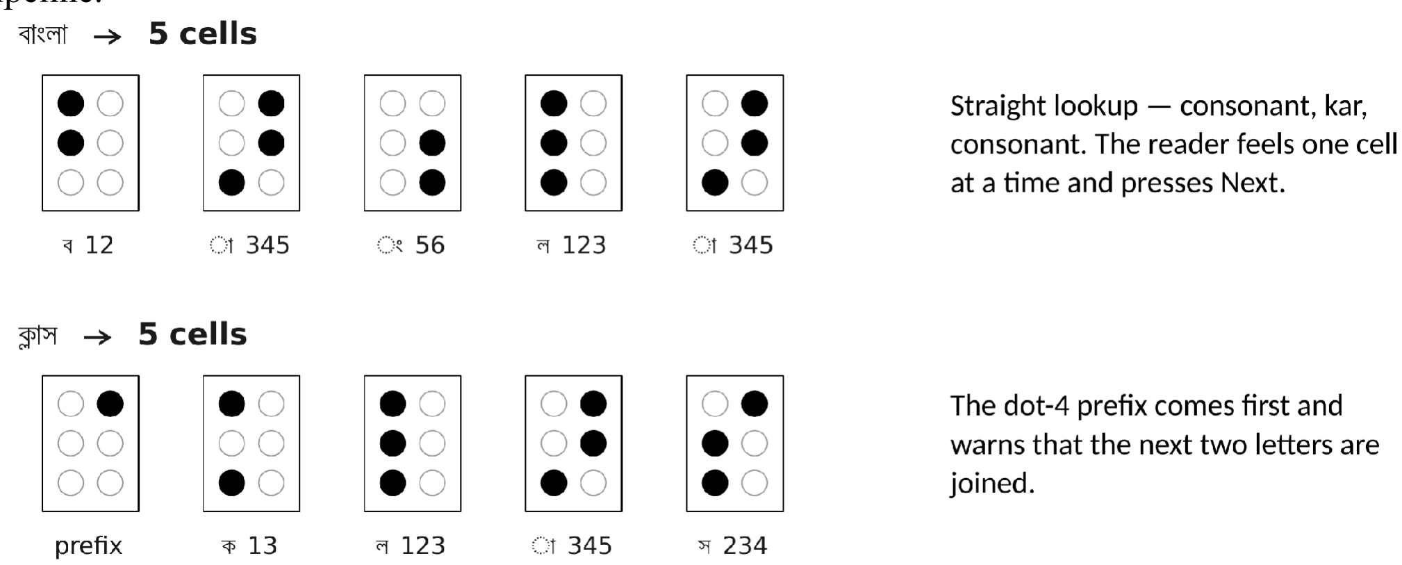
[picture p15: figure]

________________________________________________________________________________________

Figure 19: Step 2 — a dot list is converted into a one-byte mask and appended to the cell buffer.
Step 3 — Rule dispatch.
translateBangla() walks the decoded string and tests an ordered list of rules at each position. The first rule that matches wins, consumes the characters it needs and advances the index past them. The order matters: specific rules must be tested before general ones, so numbers and conjuncts are checked before plain letters, otherwise the leading consonant of a cluster would be emitted on its own before the prefix cell could be generated.

Figure 20: Step 3 — the ordered rule set applied at each position of the input string.
Step 4 — Driving the cell.
showBrailleCell() takes the byte at the current index and writes its six bits to the six GPIO pins, so exactly the dots that belong to that cell are raised. Figure 21 works two examples through the whole pipeline.

Figure 21: Worked examples: বাংলা is a straight lookup of five cells, while াস needs the dot-4 conjunct prefix before the joined consonants.

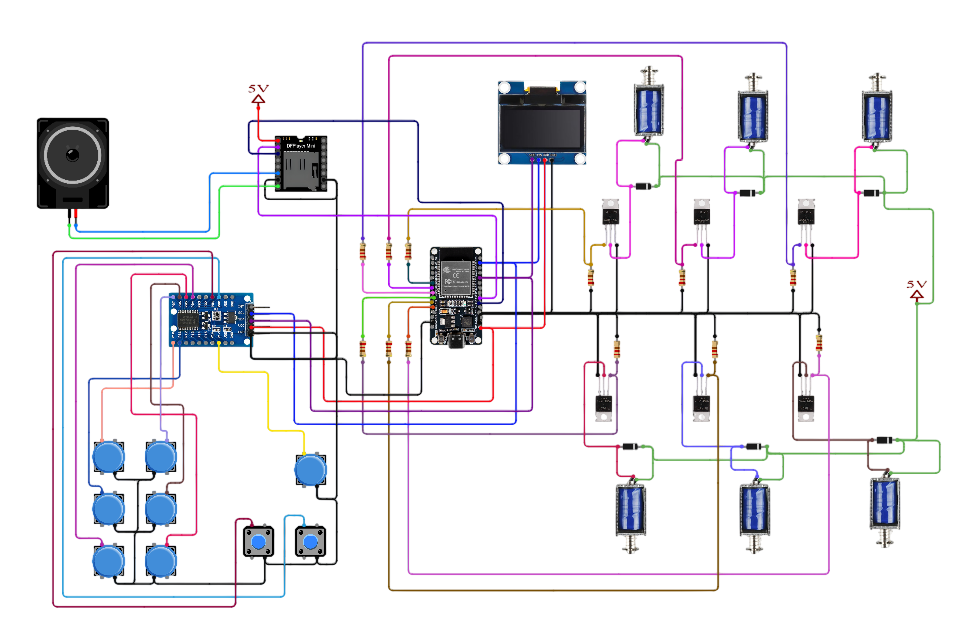
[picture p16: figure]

________________________________________________________________________________________

## 3.3 Circuit Diagram

The complete schematic of the system was captured in Cirkit Designer [14] and is reproduced in Figure
22. It shows the ESP32 at the centre with the OLED and PCF8575 on the shared I²C bus, the nine pushbuttons on the expander ports, the DFPlayer Mini and speaker on the UART, and the six identical MOSFET driver stages with their flyback diodes feeding the six solenoids of the Braille cell. The 5 V rail from the buck converter supplies the coils and the DFPlayer; the ESP32 and the logic share the same ground reference.

Figure 22: Complete circuit schematic of the bidirectional Bangla Braille translation system, drawn in Cirkit Designer [14].

## 3.4 Simulation Model

No simulation model was developed for this project. The system is predominantly a digital, firmware-driven design: the behaviour that determines whether it works is the Bangla Braille rule set and the peripheral timing, neither of which a circuit simulator can predict. The only analogue block, the solenoid driver of Section 3.2.8, is a single-transistor low-side switch whose operating point is fixed by equations (3.3) to (3.6) and can be verified by hand.
Cirkit Designer [14] was used for schematic capture and connectivity checking rather than for time-domain simulation, and correctness was established experimentally instead: each subsystem — the OLED, the PCF8575 keyboard, the DFPlayer and one solenoid channel — was built and proven on a breadboard before being merged into the single firmware and the final veroboard assembly. Those tests are reported in Section 5.3.

## 3.5 CAD/Hardware Design

A chassis was modelled in three dimensions to house the electronics and to fix the geometry that the user actually touches. The top face carries the six-dot Braille cell aperture, the six dot keys together with the MODE, ENTER/NEXT and BACKSPACE/PREVIOUS buttons, the OLED window and the speaker grille; the body encloses the veroboard assembly, the buck converter and the battery. The spacing of the solenoid plungers follows the standard Braille cell geometry so that a trained reader's

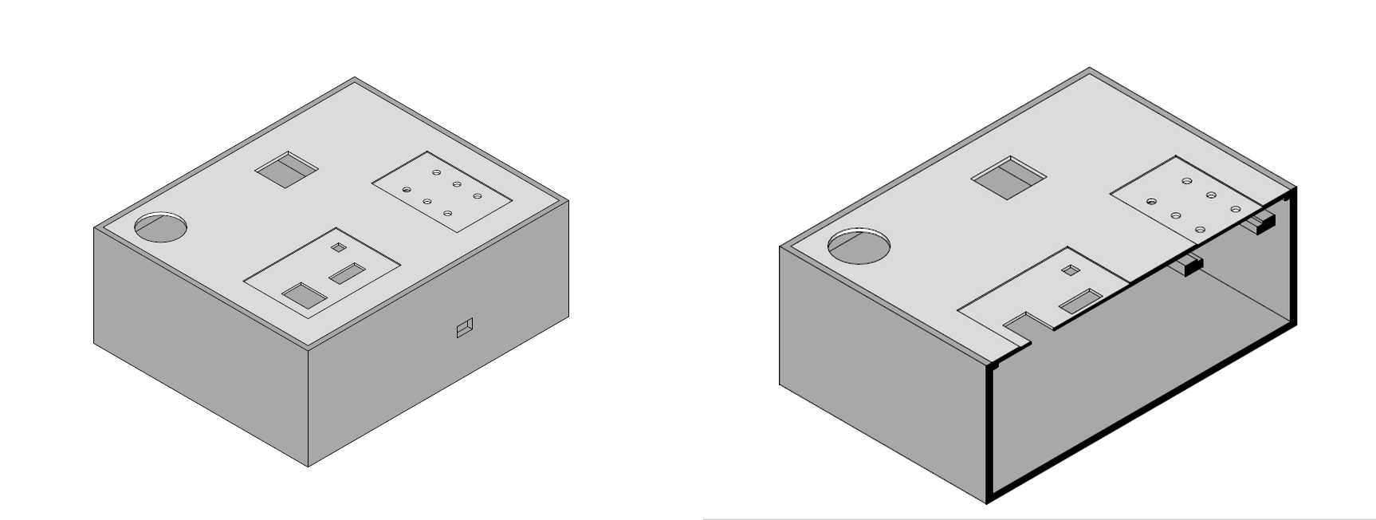
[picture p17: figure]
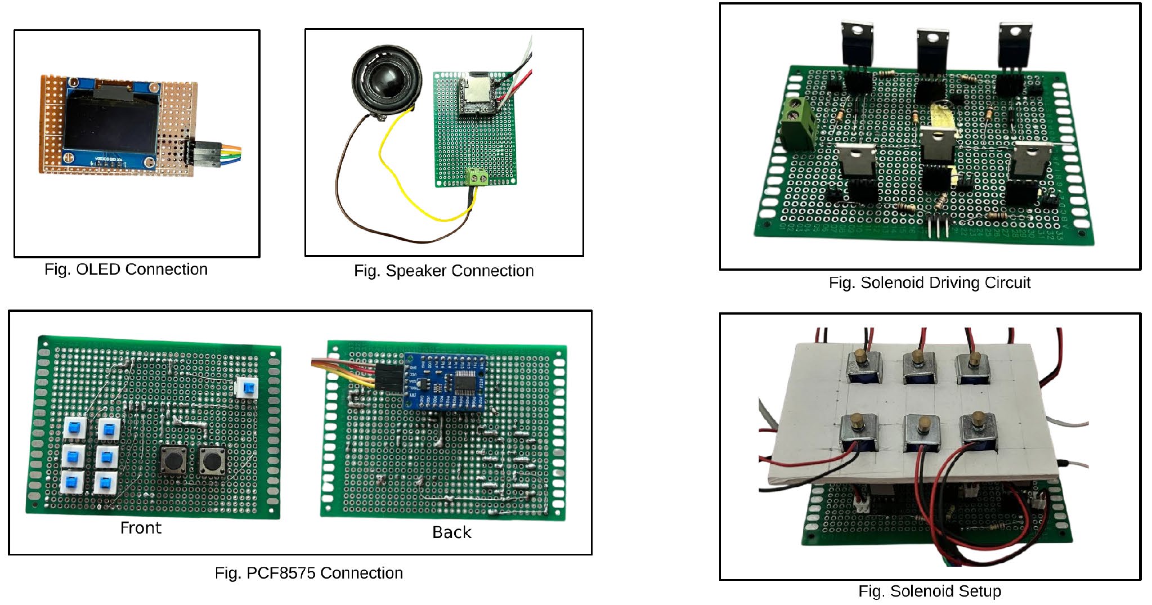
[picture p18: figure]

________________________________________________________________________________________ fingertip finds the dots where it expects them. The 3D model was outsourced under the team's design guidelines.

Figure 23: 3D CAD model of the chassis: (left) closed view showing the Braille cell aperture, keypad, display window and speaker opening; (right) cut-away view showing the internal volume for the electronics.

## 3.6 Veroboard Implementation

No printed circuit board was fabricated for this prototype. The complete circuit was instead implemented on veroboard, with the subsystems distributed over several small boards so that each could be built, tested and replaced independently: one board for the OLED, one for the DFPlayer and speaker, one carrying the PCF8575 expander and the nine pushbuttons, and one carrying the six MOSFET driver stages with the solenoid array mounted above it. Veroboard was chosen because it allowed the design to be corrected during integration; several driver connections and the button port assignment changed after the first tests, which a fabricated board would not have permitted within the project timeline. A proper PCB layout is identified as future work in Section 9.

Figure 24: Circuit implementation on veroboard: OLED board, DFPlayer and speaker board, PCF8575 and pushbutton board (front and back), the six-channel MOSFET driver board, and the solenoid array mounted over it.

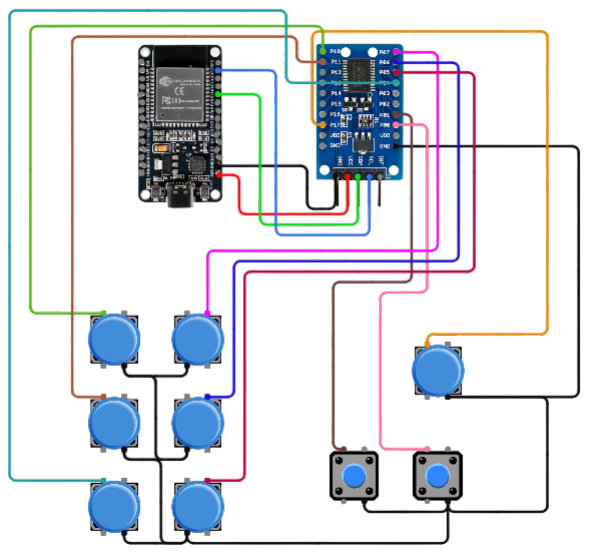
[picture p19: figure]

________________________________________________________________________________________

## 4 Implementation

## 4.1 Description

### 4.1.1. Building the Input Circuit:

To implement the input circuit, we used six latching push buttons to capture the six-dot Braille pattern. Two additional non-latching push buttons are used for Enter and Backspace. The Enter button confirms the currently selected Braille pattern and registers it as a single character, while the Backspace button removes the previously entered character in case of a mistake. A separate mode-selection button determines the operating mode: when pressed, the device operates in Input Mode, and when released, it operates in Output Mode. The Enter button is used as the Next button in reading mode (which reads the next letter and sends it to output) and the Backspace button as the Previous button (which navigates to the previous letters).
We used an I²C GPIO expander (PCF8575) to read the button inputs, reducing the number of ESP32 GPIOs required for the input interface and avoiding the use of GPIOs with boot-time strapping functions. This provides greater flexibility in GPIO allocation and minimizes the possibility of the external button circuitry interfering with the ESP32’s boot configuration. The PCF8575 communicates with the ESP32 through the existing I²C bus shared with the OLED, requiring only the SDA and SCL connections to the ESP32 (excluding VCC and GND). Thus, both devices can efficiently share the same two-wire I²C bus.

Fig 25: Schematic for input circuit

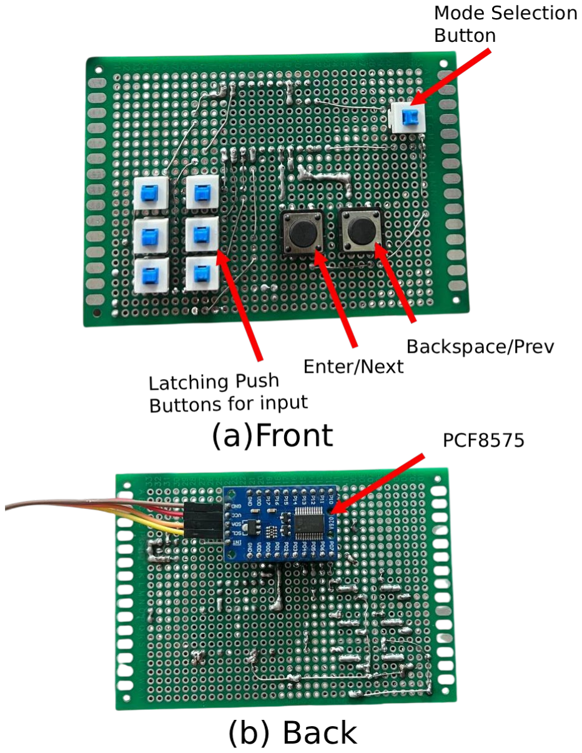
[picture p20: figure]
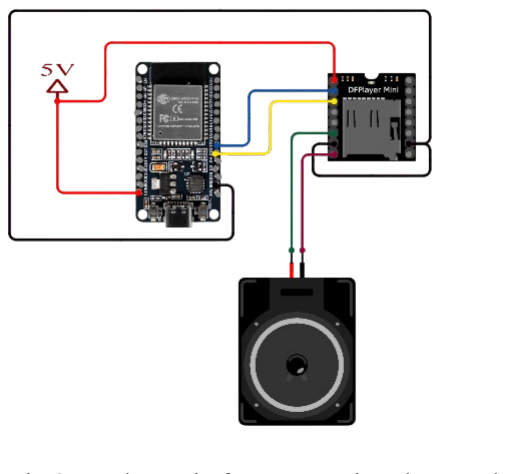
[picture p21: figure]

________________________________________________________________________________________

Fig 26: Circuit Implementation of the Input

### 4.1.2. Speaker Connection:

The audio output is implemented using a DFPlayer Mini module, which communicates with the ESP32 through UART serial communication. The ESP32 sends commands to the DFPlayer to select and play the required audio file corresponding to the detected Braille character. The DFPlayer Mini decodes the stored audio files and outputs the audio signal to the connected speaker, providing audible feedback to the user. Note that the Speaker is only used in the case of Braille Input to aid the blind person with auditory feedback so they can validate the letters they are typing.

Fig 27: Schematic for Connecting the Speaker Fig 28: Circuit Implementation of Speaker

The Rx,Tx GND and VCC pins of the schematic is different than the connection in our circuit and

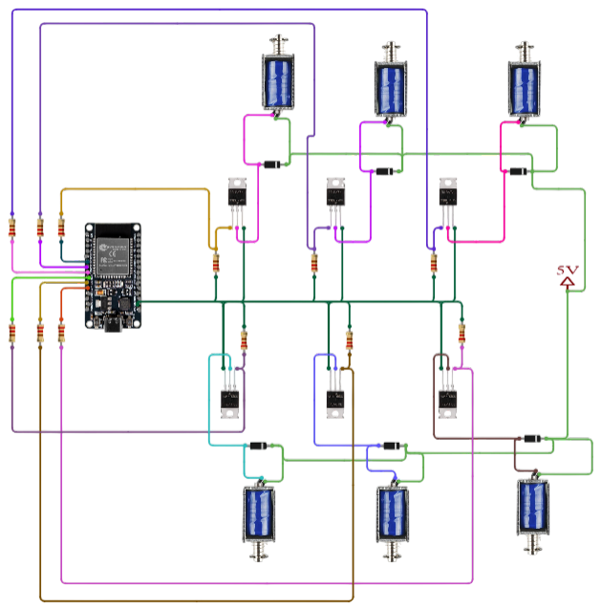
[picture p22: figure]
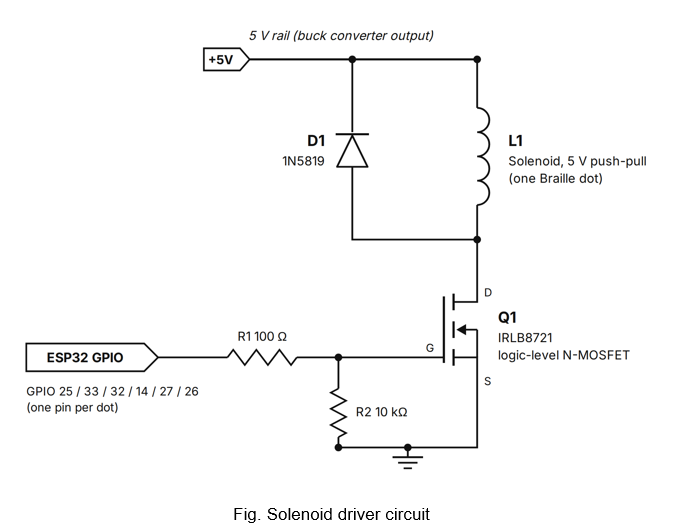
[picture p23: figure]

________________________________________________________________________________________ that’s because the DF mini has different versions. The plus side of the speaker is connected to SPK+ and the minus side is connected to SPK- pins.
The DFPlayer Mini can only play audio files that have been pre-recorded and stored on its memory card; it does not generate speech or convert text into audio. Therefore, we had to create and store individual audio files for the required characters and establish a mapping between each character and its corresponding audio file.

### 4.1.3. Building the Output Circuit:

For implementing the output side, we used six push-pull solenoids that are driven by 6 MOSFETs. We do not control the Solenoids directly by the ESP32 5V because it is unable to supply the huge current required by the solenoids. Instead, we drive 6 MOSFET gates by the 3V from ESP GPIO output pins, and we connect a 5 Volt DC output from a LiPO+Buck Converter to the MOSFET’s drain that supplies the solenoids their desired current. All the 6 solenoids are connected in parallel with the 5V source which can simultaneously drive them with their required current rating. After decoding the letters from the text sent over Wifi hosted webpage, the gating signals are sent to the correct GPIO pins corresponding to the correct dot positions and the MODFETS, in turn drives the solenoids that raise those particular dots.

Fig 29: Schematic for the Solenoid Driving Circuit

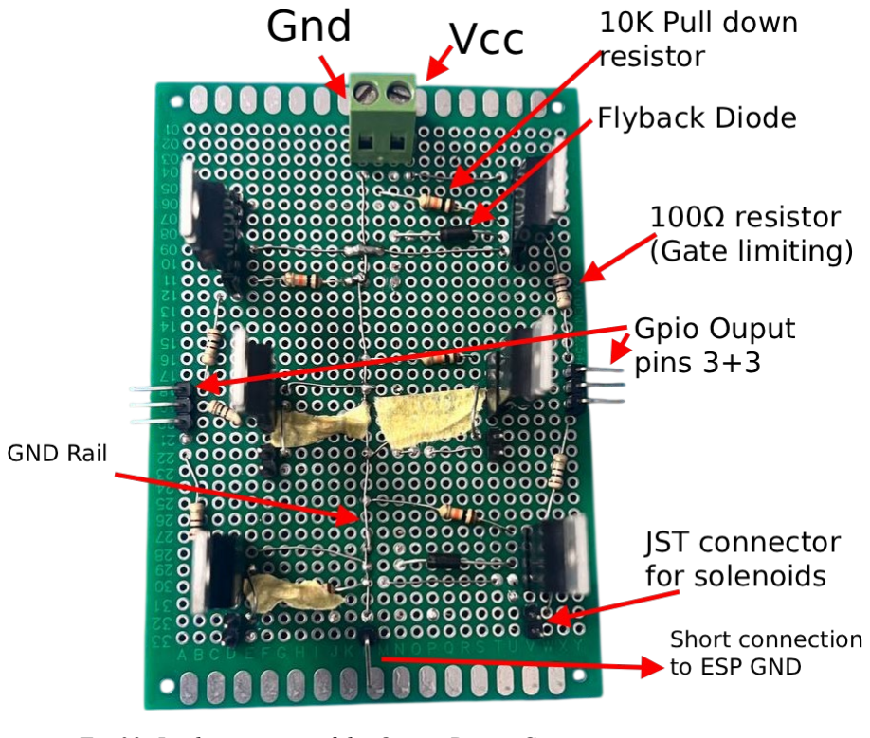
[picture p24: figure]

________________________________________________________________________________________

Fig 30: Implementation of the Output Driver Circuit

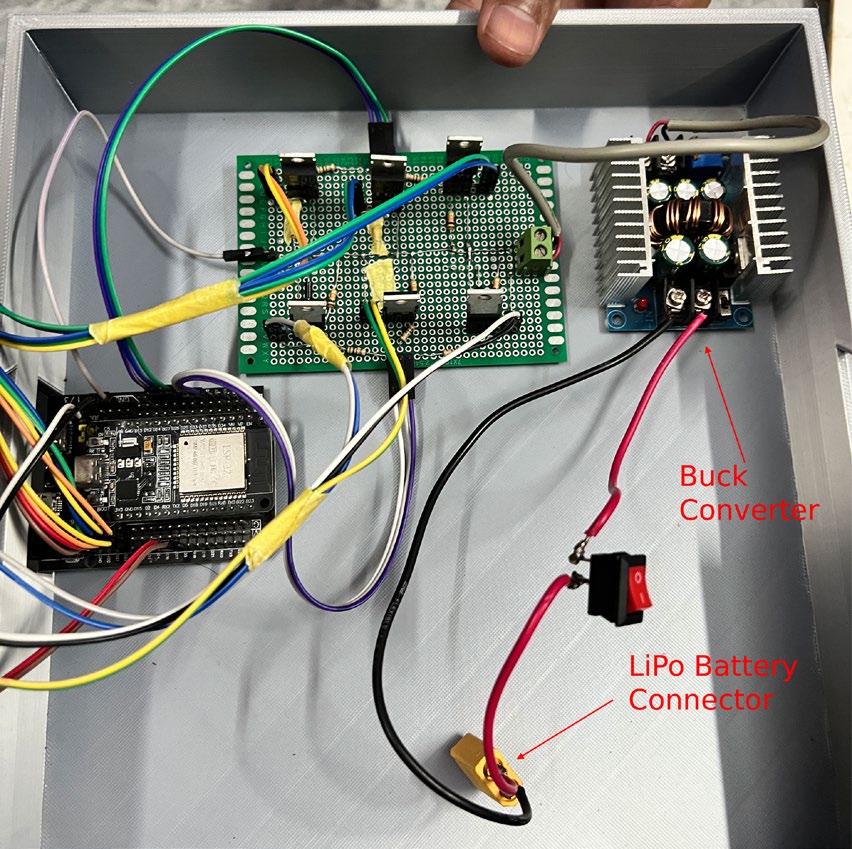
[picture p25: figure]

________________________________________________________________________________________

Fig 31: (Left) Connection of the whole output circuit with the power source and ESP32 (Right) After connecting to the solenoids

### 4.1.4. The OLED Display:

The OLED display is used for a trainer or some assisting person who is helping the blind person to navigate the device. It shows both the text given as input and also the output text that is sent over the hosted webpage. This works with I2C protocol and only has 4 pins VCC,GND,SCL,SDA. The I2C bus is shared with the MUX and causes no vital issue.

Fig 32: Schematic of the OLED | Fig 33: Implementation on the veroboard

### 4.1.5. Integrating the Complete System:

A custom 3D-printed casing is used to assemble the separate components into a cohesive device. The ESP, battery source, I/O expander, and the Buck Converter are kept inside the box.


________________________________________________________________________________________

Fig. 31: Integration of all the components

## 5 Design Analysis and Evaluation

## 5.1 Novelty

1. Use of exact Bangla Braille Grammar: Our system incorporates the linguistic structure of Bangla with proper Braille grammar, including vowel signs (কার), conjunct consonants (যুার), punctuation, numbers, and even decimals. Instead of defining our own made up rules, we used the exact rules Braille is written and read in Bangla language that will make the user experience more natural.
2. Bidirectional Braille Interaction: The device supports both Braille input and Braille output. Users can enter Braille characters through the six-button input interface, while the device translates Bangla text and represents it physically through the tactile Braille output interface. It is hard to find a device that works both ways, especially when resources are scarce in the Bangla language.
3. Integrated audio feedback: Our DFPlayer+speaker can provide audio feedback for Braille input. So a user entering a Braille pattern can hear the corresponding character and validate the input he/she just entered.
4.Standalone Operation: The device performs the Bangla-to-Braille translation and controls the tactile and audio outputs directly through the ESP32, allowing the system to operate independently without requiring a computer for processing.

________________________________________________________________________________________

## 5.2 Design Considerations (PO(c))

### 5.2.1 Considerations for public health and safety

- The device was designed with safe, low-voltage electronic components to minimize the risk of electrical hazards during operation. Also we kept everything inside a plastic box which ensures the user does not accidentally touch any electrical components that can cause short circuit.
- The tactile solenoids are controlled through appropriate driver circuits rather than directly from the ESP32 GPIO pins, preventing excessive current from being drawn from the microcontroller and causing unwanted harm. Gate current limiting resistors are used in the mosfets and the current and ratings are matched for safe operation. Flyback diodes are used so that while discharging the solenoids don’t harm the circuit.
- The solenoids are not held in charged position for more than 3 seconds at a time ensuring the coils do not heat up excessively. Instead we “flash” each letter for 3 seconds at a time give it a gap and then repeat again.

### 5.2.2 Considerations to environment

The prototype uses reusable electronic components such as the ESP32, OLED display, PCF8575 module, DFPlayer Mini, and solenoids. The system is also designed around a rechargeable LiPo battery, reducing the need for disposable batteries. However, the solenoids consume relatively high electrical power. Future improvements should therefore focus on reducing power consumption and improving the efficiency of the tactile Braille mechanism. Electronic components and batteries should also be disposed of properly at the end of their useful life.

### 5.2.3 Considerations to cultural and societal needs

- The device is specifically designed to support Bangla Braille, addressing the needs of Bangla-speaking visually impaired users. This device works as a all in one solution for both bangla braille typing and reading from text file dynamically.
- The translation system considers Bangla-specific linguistic structures, including vowel signs (কার), conjunct consonants (যুার), punctuations and numbers. Thus it adds to the cultural significance
- Audio feedback is also incorporated to improve accessibility and assist users in identifying and verifying the entered Braille characters

## 5.3 Limitations of Tools (PO(e))

- Single Braille Cell: Only one six-dot Braille cell is used; therefore, long text must be read one character at a time.
- Limited Memory: Only a fixed amount of Braille data can be stored at a time.
- Pre-recorded Audio: Audio feedback depends on MP3 files stored on the microSD card.
- No Automatic Voice Generation: The system cannot automatically generate speech for complete words or sentences.
- Local Wi-Fi Access: The webpage works only through the local Wi-Fi network created by the ESP32.

________________________________________________________________________________________

- Limited Character Support: Some punctuation marks and complex symbols are not supported in the current system.
- High Power Consumption: The solenoids require relatively high current during operation.
- Solenoid Heating and Speed: The solenoids are comparatively slow and may generate heat during prolonged operation.

## 5.4 Impact Assessment (PO(f))

### 5.4.1 Assessment of Societal and Cultural Issues

The proposed system may help improve communication between Bangla Braille users and people who do not know Braille. Its bidirectional operation can support communication in educational and everyday environments. The system may also assist in Bangla Braille education and practice. The Braille input interface can additionally serve as a basic typing mechanism for visually impaired users. Because the device specifically processes Bangla Braille, it addresses a language-specific accessibility requirement rather than relying only on systems designed for other languages.

### 5.4.2 Assessment of Health and Safety Issues

The tactile Braille output provides information without requiring the user to depend on a visual interface. This is particularly relevant for visually impaired users. Electrical and mechanical safety were also considered in the hardware design. The solenoids are controlled through driver circuits rather than directly from the ESP32, and protective components are used in the switching circuit. Nevertheless, solenoid heating and high current consumption remain important considerations for prolonged operation and should be further improved in future designs.

### 5.4.3 Assessment of Legal Issues

The Bangla text entered by the user is processed locally by the ESP32 web server. Therefore, the basic operation of the prototype does not require the entered text to be sent to an external cloud server. The developed prototype is intended as an educational assistive system and should not be presented as a certified commercial accessibility or medical device without appropriate testing, validation, and certification.

## 5.5 Sustainability Evaluation (PO(g))

The proposed system has potential for further development as a low-cost assistive technology. The ESP32-based architecture allows several functions—including processing, Wi-Fi communication, webpage hosting, and hardware control—to be

________________________________________________________________________________________ integrated into a single controller. The sustainability of the design can be improved by replacing the Veroboard implementation with a compact custom PCB, reducing the power consumption of the tactile output mechanism, and improving the mechanical design of the Braille cell. The use of a rechargeable power source can also reduce dependence on disposable batteries. A major concern is the relatively high power requirement and heating of the solenoids. Therefore, future versions should use a more energy-efficient tactile actuation mechanism or optimized solenoid control to improve long-term sustainability.

## 5.6 Ethical Issues (PO(h))

Throughout the development of the device, we maintained professional integrity by accurately documenting the design, implementation, testing, and limitations of the system without overstating its capabilities. We followed responsible engineering practices by prioritizing user safety during circuit design and testing, using components and software in accordance with their intended requirements, and properly acknowledging externally sourced materials. Privacy was also considered when handling uploaded text and user inputs, ensuring that the system did not unnecessarily collect or retain personal information.

________________________________________________________________________________________

## 6 Reflection on Individual and Team work (PO(i)

## 6.1 Individual Contribution of Each Member

Member | Student ID | Main Contribution
Mushfiqur Rahman | 2106181 | Bangla text processing(Conjunct, Punctuation, numbers, special characters), Text to Braille processing, Circuit soldering, Total system integration, Documentation
Chayan Paul | 2106182 | Braille to audio processing, DFPlayer Bug fix, Solenoid circuit operation, Logistics, System integration, Documentation
Shamin Yeaser | 2106183 | Bangla text processing(Kar, Conjunct), DFPlayer testing, Display setup for Bangla text, System integration, Logistics, Documentation
Kayes Sami Malitha | 2106184 | Webpage hosting, Circuit soldering, audio file conversion, Logistics, System integration, Documentation

## 6.2 Mode of Teamwork

The project was developed using a collaborative approach. At the beginning, the complete system was divided into several smaller subsystems, such as Bangla text processing, Braille input processing, audio feedback, OLED display, webpage hosting, solenoid control, and hardware implementation.
Individual members initially worked on their assigned tasks. After completing the individual modules, the modules were gradually combined into a single ESP32-based system. During integration, all members participated in testing, debugging, circuit checking, and modification of the firmware.
Regular discussions among the members were important because most parts of the project were dependent on each other. For example, the Bangla processing algorithm had to work correctly with the Braille lookup table, while the generated Braille pattern had to match the

________________________________________________________________________________________ physical output produced by the six solenoids. Similarly, Braille input had to be coordinated with the OLED and audio feedback systems.
Therefore, the project required both individual responsibility and continuous teamwork.

## 6.3 Diversity Statement of Team

The project team consisted of four members with different technical responsibilities and problem-solving roles. This diversity of tasks helped the team address different aspects of the system, including embedded programming, Bangla Unicode processing, hardware implementation, audio processing, web development, and documentation.
Team members shared their individual findings with the rest of the group during system integration. Decisions related to hardware connections, software logic, debugging, and presentation were made through group discussion. This collaborative environment helped combine different technical skills into a complete working prototype.

## 6.4 Log Book of Project Implementation

Date | Milestone achieved | Individual Role | Team Role | Comments
Week 6 | Literature review on Bangla Braille rules and Bangla text processing rules | 2106183 reviewed Braille rules and 2106181 reviewed Bangla text processing rules | Team discussed translation rules | Translation pipeline approach finalized
Week 6 | Bangla text rendering on OLED | 2106181 reviewed BanglaText library and 2106182 and 183 implemented line processing | Team verified Bangla text rendering cases | Bangla text rendering approach finalized
Week 7 | Webpage hosted using ESP32 | 2106184 implemented the webpage and received Bangla text over wifi | Team implemented text validation rule | Text entry over wifi finalized
Week 7 | Reading Braille dots from 6 push buttons | 2106183 implemented algorithm for Braille reading and implemented normal character processing | Team verified operation | Braille pattern reading algorithm finalized
Week 8 | Implementing Kar and conjunct | 2106183 and 181 implemented kar and conjunct operation. | Team verified the operation | Braille processing rule added

________________________________________________________________________________________

Week 8 | Implemented ৎ and ঋ | 181 modified the algorithm to include the characters. 182 and 184 performed debugging. | Team verified operation | Braille rule enhanced
Week 9 | Solenoid operation circuit verified | 182 implemented the solenoid driver circuit | Team verified the operation | Solenoid operated
Week 9 | I/O expander operated | 181 implemented the I/O expander. 184 helped | Team verified pushbutton operation | I/O expander operated
Week 10 | Bangla to Braille translation pipeline finalized | 181 implemented the algorithm and 183 added the next/previous feature. | Team verified operation | Bangla to Braille translation verified on LED for simplicity
Week 11 | Speaker operated using DFPlayer | 182 and 183 implemented the circuit and code | Team verified operation | Speaker operated
Week 11 | Circuit implemented on veroboard | 184 and 181 soldered the circuits on the veroboard and 182 helped | Team discussed the system architecture | Circuit implementation completed
Week 12 | Added numbers and punctuation | 181 added numbers and punctuation | Team performed debugging | Number mode implemented
Week 13 | Final debugging and code verification | 182 and 183 performed final proofreading | Team verified operation | Code finalized
Week 14 | 3D model assembly | 183 managed the model design, 184 and 181 assembled the system | Team verified correct operation | Project completed
Week 14 | Documentation completed | All performed | Team organized the project documents | Report, presentation, poster prepared

## 7 Communication to External Stakeholders (PO(j))

## 7.1 Executive Summary

The Bidirectional Bangla Braille Translation System is an ESP32-based assistive device designed to improve communication between Bangla Braille users and people who do not understand Braille. The device supports communication in both directions. A user can enter a six-dot Braille pattern and obtain the corresponding Bangla character through an OLED display and audio feedback. In the opposite direction, Bangla text can be entered through a locally hosted webpage and converted into tactile Braille using a six-solenoid refreshable Braille cell. The prototype combines tactile, visual, and audio feedback in a low-cost

________________________________________________________________________________________ embedded platform and demonstrates a practical approach to Bangla Braille communication.


________________________________________________________________________________________

## 7.2 User Manual

The device has two main operating modes: Braille-to-Bangla and Bangla-to-Braille.

________________________________________________________________________________________

## 7.3 Github Link

https://github.com/intmushfiq/Bidirectional-Bangla-Braille-Device

## 7.4 YouTube Link

https://youtu.be/4rY5ggd-0BE

________________________________________________________________________________________

## 8 Project Management and Cost Analysis (PO(k))

## 8.1 Bill of Material

Item | Qty | Unit(TK) | Total(TK)
ESP32 DevKit (30-pin) | 1 | 480 | 480
SH1106 OLED 1.3″ (I²C) | 1 | 600 | 600
PCF8575 I/O expander module | 1 | 350 | 350
DFPlayer Mini | 1 | 240 | 240
32 GB microSD | 1 | 650 | 650
4 Ω 3 W speaker | 1 | 280 | 280
5 V push-pull solenoid | 6 | 250 | 1500
IRLB8721 MOSFET | 6 | 150 | 900
1N5819 diode, resistors | — | — | 50
Push buttons (6 latching, 3 other) | 9 | 10 | 90
LiPo Battery + Buck Converter | 1 | 2200 | 2200
Veroboard, wires, enclosure | — | — | 500
Enclosure (3D Printing) | 1 | 3000 | 3000
Prototype total | | | 10,840

________________________________________________________________________________________

## 8.2 Calculation of Per Unit Cost of Prototype

The approximate cost of one prototype is 10840 Tk.

## 8.3 Calculation of Per Unit Cost of Mass-Produced Unit

The per-unit cost can be reduced when the device is produced on a larger scale. This can be achieved by purchasing components in bulk, using a custom PCB instead of separate modules and Veroboard, and optimizing the power supply and hardware design.
Based on these considerations, the estimated cost of one mass-produced unit is approximately BDT 6,500, which represents a cost reduction of approximately 35–40% compared with the prototype.

________________________________________________________________________________________

## 9 Future Work (PO(l))

- Add multiple Braille cells for faster reading.
- Design PCB layout for a compact device.
- Add Bangla text-to-speech instead of recorded audio.
- Support more Bangla punctuation marks and symbols.
- Add English or other language processing capability.
- Improve the Braille cell design.
- Reduce power use and heating.
- Test the device with visually impaired users and Braille teachers

## 10 References

1] American Foundation for the Blind, “Refreshable Braille Displays.” [Online]. Available: afb.org/blindness-and-low-vision/using-technology/assistive-technology-products/refreshable-braille

[2] C. Chong, “The Orbit Reader 20: The Most Inexpensive Braille Display,” Braille Monitor, NFB, Oct. 2017.
[3] “েইল পিত,” উইিকিপিডয়া (Bangla Wikipedia). [Online]. Available: https://bn.wikipedia.org/wiki/েইল_পিত (accessed Sep. 25, 2026).
[4] Shop4specials Pvt. Ltd., “Humanware Refreshable Braille Display Brailliant BI 40X with Audio,” IndiaMART. [Online]. Available: https://www.indiamart.com/proddetail/humanware-refreshable-braille-display-brailliant-bi-40x-with-audio-27011004962.html (accessed Sep. 25, 2026).
[5] M. S. Rahman, M. M. Rahman and M. Kaykobad, “Bangla Braille Adaptation,” in Technical Challenges and Design Issues in Bangla Language Processing, IGI Global, 2013, ch. 2, pp. 17–34.

________________________________________________________________________________________

[6] World Braille Usage, 3rd ed. Watertown, MA, USA: Perkins; Toronto, ON, Canada: International Council on English Braille; Washington, DC, USA: National Library Service for the Blind and Physically Handicapped, Library of Congress, 2013, “Bangladesh,” pp. 9–10. ISBN 978-0-8444-9564-4.
[7] M. Kamal, A. A. Ali, M. A. H. Khan and M. Shoyaib, “Braille to Text Translation for Bengali Language: A Geometric Approach,” arXiv:2012.01494, 2020.
[8] U. W. Tabassum, S. N. Soumma, T. Tasfia and A. S. Gupta, “Design & Fabrication of a Cost-effective, Refreshable Mechanical Braille Display for Visually Impaired Students in Bangladesh,” SSRN 4862819.
[9] Science Buddies, “Build a Refreshable Braille Display with Arduino.” [Online]. Available: sciencebuddies.org
[10] Espressif Systems, ESP32 Series Datasheet; Texas Instruments, PCF8575 datasheet; DFRobot, DFPlayer Mini wiki; Infineon, IRLB8721 datasheet.
[11] M. Mazid, BanglaText — Bangla text rendering library for microcontrollers. [Online]. Available: github.com/mamunul/BanglaText
[12] O. Kraus, U8g2 graphics library for monochrome displays. [Online]. Available: github.com/olikraus/u8g2
[13] M. Zaman (lifeparticle), “Bengali-Alphabet,” GitHub repository, MIT License. [Online]. Available: https://github.com/lifeparticle/Bengali-Alphabet (accessed Sep. 25, 2026).
[14] Cirkit Designer, online circuit design and simulation tool. [Online]. Available: https://www.cirkitdesigner.com (accessed Sep. 25, 2026).

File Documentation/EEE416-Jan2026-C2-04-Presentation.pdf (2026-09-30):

30/09/2026

1

## EEE xxx – Course Title Laboratory

# Jan 202x Level-x Term-I Section Z

# Final Project Demonstration

BANGLADESH UNIVERSITY OF ENGINEERING AND TECHNOLOGY DEPARTMENT OF ELECTRICAL AND ELECTRONIC ENGINEERING

# DESIGN AND IMPLEMENTATION OF A BIDIRECTIONAL BANGLA BRAILLE TRANSLATION SYSTEM

Mushfiqur Rahman
2106181

Chayan Paul
2106182

Shamin Yeaser
2106183

Kayes Sami Malitha
2106184

SUBMITTED BY – GROUP 04

# EEE 416- Microprocessor and Embedded Systems Laboratory Jan 2026 level-4 Term-1 Section C Final Project Presentation

Outline; 1 Summary; 2 Introduction; 3 Design; 4 Implementation; 5 Design Analysis and Evaluation; 6 Reflection on Individual and Team Work; 7 Communication to External Stakeholders; 8 Project Management and Cost Analysis; 9 Future Work; 10 References

EEE 416 (2026) – Project Group C2.04 | Design and Implementation of a Bidirectional Bangla Braille Translation System | 2

2

# 1. Summary

Bidirectional Bangla Braille Communication System - A device that does both Bangla to Braille

## and Braille to Bangla translation


EEE 416 (2026) – Project Group C2.04 | Design and Implementation of a Bidirectional Bangla Braille Translation System | 3

# 2. Introduction

EEE 416 (2026) – Project Group C2.04 | Design and Implementation of a Bidirectional Bangla Braille Translation System | 4

## The problem

### - Braille is the main reading and writing medium for blind people, but most sighted family members, teachers and classmates cannot read it — a two-way communication

gap.

### - Commercial refreshable Braille displays are built for other languages and are priced far beyond most Bangladeshi learners [1], [2]. • Our goal: a low-cost, single-cell device that works in

### both directions for Bangla Braille → Bangla text +

speech, and Bangla text → tactile Braille.

US$ 3,500–15,000

Typical price of a refreshable Braille display [1]

US$ 449

Cheapest 20-cell display on the market we found (Orbit Reader 20) [2]

Fig. Embossed Braille text. Source: [3]

Fig. HumanWare Brailliant BI 40X refreshable Braille display. Source: [4]

3

# 3.1 Design: Problem Formulation

- Designing a six-dot physical Braille keyboard. • Converting Braille patterns into corresponding Bangla characters. • Supporting Bangla vowels, consonants, kar signs, conjuncts, numbers,

punctuation and special Braille sequences. • Displaying generated Bangla text and providing audio feedback. • Receiving Bangla text through an ESP32-hosted webpage. • Converting Bangla text into six-dot Braille patterns and producing physical

Braille output using six solenoids. • Allowing navigation through Braille cells using NEXT/PREVIOUS controls and

providing READ/WRITE mode switching.

EEE 416 (2026) – Project Group C2.04 | Design and Implementation of a Bidirectional Bangla Braille Translation System | 5

# 3.1.1 Identification of Scope

# 3.1 Design: Problem Formulation

EEE 416 (2026) – Project Group C2.04 | Design and Implementation of a Bidirectional Bangla Braille Translation System | 6

# 3.1.2 Literature Review

Existing work | What it does | Gap for our problem
Rahman, Rahman & Kaykobad — Bangla Braille Adaptation [5] | Defines the Bangla Braille code: letters, kar, conjunct and number rules | A standard only — no device
World Braille Usage, 3rd ed. — Bangladesh chart [6] | Official Bangla Braille cell for every letter, kar, sign, digit and punctuation mark | Reference chart only — no device
Kamal et al. — Braille-to-text for Bengali [7] | Scanned embossed Braille → Bangla text (97.25 % accuracy) | One direction; needs a scanner; no tactile output
Tabassum et al. — low-cost mechanical Braille display for Bangladeshi students [8] | Refreshable tactile display hardware | Output only; no Braille typing or text entry
Orbit Reader 20 (commercial) [2] | 20-cell refreshable display, Bluetooth / USB | US$ 449; not built around Bangla rules
Arduino refreshable Braille cell project [9] | Single DIY cell driven by a microcontroller | English letters, one direction only
Our Project | Braille ⇄ Bangla in one device, with OLED, audio feedback and web input | Handles kar, silent অ, conjuncts, ঋ / ৎ and numbers

4

# 3.1 Design: Problem Formulation

There are two main conversion problems:

### 1. Braille → Bangla

Workflow : 6 Braille Keys → Braille Pattern → Bangla Character → OLED + Audio
- Recognize 6-dot Braille patterns
- Handle Bangla characters and combinations
- Provide text and audio output

### 2. Bangla → Braille

Workflow : Bangla Text → Unicode Processing → Braille Pattern → Solenoid Output ◦ Process Bangla text from webpage

- Convert characters into Braille patterns
- Generate physical Braille using solenoids

Mode Switching: Preserve the current text and Braille position when changing modes.

EEE 416 (2026) – Project Group C2.04 | Design and Implementation of a Bidirectional Bangla Braille Translation System | 7

# 3.1.3 Formulation of Problem

# 3.1 Design: Problem Formulation

EEE 416 (2026) – Project Group C2.04 | Design and Implementation of a Bidirectional Bangla Braille Translation System | 8

# 3.1.4 Analysis

Decision | Options considered | Chosen and why
Tactile actuator | Piezo cell, servo, solenoid | Solenoid: low cost, fast, simple on/off drive
Solenoid driver | Direct GPIO, BJT, logic-level MOSFET | IRLB8721 MOSFET: full turn-on at 3.3 V, low loss; flyback diode protects it [10]
Button inputs | 9 direct GPIOs, I/O expander | PCF8575: 9 buttons on the shared 2-wire I²C bus, frees GPIOs [10]
Audio feedback | Cloud text-to-speech, pre-recorded clips | DFPlayer + microSD: instant playback, works offline [10]
Bangla text input | Hand-made bitmaps, font library File upload to flash, live web form | ESP32 web page: any phone or PC, no app or router needed Bangla display BanglaText + U8g2: shapes kar and conjuncts

automatically [11], [12]

5

# 3.2 Design Methods

EEE 416 (2026) – Project Group C2.04 | Design and Implementation of a Bidirectional Bangla Braille Translation System | 9

## 3.2.1 Hardware components and software

Component | Role in the system
ESP32 DevKit (30-pin) | All logic, Wi-Fi access point and web server
OLED Display | Shows Bangla text in both modes
PCF8575 I/O expander | Reads 6 dot keys, ENTER/NEXT, BACKSPACE/PREVIOUS, MODE
DFPlayer Mini + microSD + speaker | Plays 104 pre-recorded Bangla clips
5 V 1A push-pull solenoids × 6 | One refreshable tactile Braille cell
IRLB8721 MOSFET + 1N5819 × 6 | Logic level switch and flyback protection
LiPo Battery and Buck Converter | 5 V supply for solenoids and DFPlayer

3.2 Design Methods; needed; • ESP32 works as a Web Server; IP Address; 3.2.2 Website Hosting

- ESP32 creates its own Wi-Fi Access Point — no external router
- Necessary HTML code is written inside the header file WebPage.h Wi-Fi Name Braille_Bangla | Password
192.168.4.1 | The ESP32-hosted webpage — বাংলা ইল অনুবাদক
EEE 416 (2026) – Project Group C2.04 | Design and Implementation of a Bidirectional Bangla Braille Translation System | 10

# 3.2 Design Methods

## 3.2.3 Receiving and Cleaning the Input

User types Bangla text; Presses Send button; /send route; handleSend() function; ESP32 receives & stores text; Example; Before cleaning; After cleaning; EEE 416 (2026) – Project Group C2.04; Design and Implementation of a Bidirectional Bangla Braille Translation System; Cleaned Text; Characters; YES; OLED message: দয়া কের বাংলা িলখুন

Input Cleaning Rules
• Enter / new-line characters → converted to spaces
• Extra spaces at the start and end → removed

handleSend() cleans the text before checking it for Bangla.

3.2 Design Methods
3.2.4 Input Text Validation

Check Bangla Unicode Range (U+0980 – U+09FF) & Other Allowed

Any Non-Bangla Characters Found?

Continue to Braille translation

Show warning; solenoids OFF

showing the Bangla-only warning message

Speaker: Warning Sound

7

3.2 Design Methods; 1. Bangla Text Input; 2. ESP32 Receives Text; 3. Bangla Font Rendering; 4. Pixel Mapping & Buffering; 5. OLED Display Output; Key idea:; Source: BanglaText library [11]

## A Bangla text processing library, named BanglaText by Mamunul Mazid, is used. The library

contains the font header file, which stores the Bangla character glyphs and its pixel mapping.

EEE 416 (2026) – Project Group C2.04 | Design and Implementation of a Bidirectional Bangla Braille Translation System | 13

## 3.2.5 Displaying Bangla Text on the OLED


EEE 416 (2026) – Project Group C2.04 | Design and Implementation of a Bidirectional Bangla Braille Translation System | 14

# 3.2 Design Methods

### - DFPlayer is used here to read the pre-recorded mp3 files from the microSD card [13] - 4 ohm, 3 watt speaker is used to play the mp3 files

## 3.2.6 Audio Output: DFPlayer Mini and Speaker

8

EEE 416 (2026) – Project Group C2.04 | Design and Implementation of a Bidirectional Bangla Braille Translation System | 15

# 3.2 Design Methods

A particular braille pattern is pressed and entered.

### The pattern is decoded to a bangla character

The esp32 sends the particular encoding number to the DFPlayer.

The DFPlayer then reads that particular mp3 file like the mp3 file of ‘ক’ So ‘ক’ is played on the speaker

## Features:

Here we used some other mp3 files for new line, backspace, space, invalid input etc and played that on the speaker. Also

### there are in total 104 mp3 files. [13]

## 3.2.7 Audio Feedback Workflow

# 3.2 Design Methods


EEE 416 (2026) – Project Group C2.04 | Design and Implementation of a Bidirectional Bangla Braille Translation System | 16

### MOSFET switch

- IRLB8721 is logic-level: it turns on fully from the 3.3 V GPIO.
- 10 kΩ pull-down keeps the solenoid off while the ESP32 boots; 100 Ω limits gate charging current.

### Flyback diode

- Switching off a coil gives V = L·di/dt spikes; the 1N5819 Schottky provides a freewheeling path to handle these spikes.

Fig. Solenoid driver circuit

## 3.2.8 Solenoid Driver Stage (repeated for all six dots)

9

# 3.2 Design Methods


EEE 416 (2026) – Project Group C2.04 | Design and Implementation of a Bidirectional Bangla Braille Translation System | 17

## 3.2.9 Pushbutton Input Subsystem

# 3.2 Design Methods


EEE 416 (2026) – Project Group C2.04 | Design and Implementation of a Bidirectional Bangla Braille Translation System | 18

## 3.2.10 Complete Wiring of the Device

10

# 3.2 Design Methods

EEE 416 (2026) – Project Group C2.04 | Design and Implementation of a Bidirectional Bangla Braille Translation System | 19

## 3.2.11 Power Budget and Driver Calculations

Load | Current (approx.)
6 solenoids × 1 A (worst case: all dots raised) | 6.0 A
ESP32 with Wi-Fi access point (peaks) | 0.5 A
DFPlayer Mini + 3 W speaker | 0.6 A
OLED + PCF8575 | < 0.05 A
Total | ≈ 7.2 A → 36 W

# 3.2 Design Methods

## 3.2.12 Braille Input – Case 1: Dependent Vowels (কার)

## In Braille, independent vowels (ex. আ, ই) and dependent vowels (◌া, ি◌) DO NOT have a

different braille pattern. If a vowel appears directly after a consonant, it is considered as a

## dependent vowel and is rendered as a কার-attached consonant form. [5], [6]

মা


EEE 416 (2026) – Project Group C2.04 | Design and Implementation of a Bidirectional Bangla Braille Translation System | 20

11

# 3.2 Design Methods

## 3.2.12 Braille Input – Case 2: Independent Vowels (রবণ)

- If a word starts with a vowel, it is rendered as the standalone vowel. • If a vowel comes after a closed form consonant ending with “the অ” sound, the vowel is

## kept as independent and not combined to form a কার. [5], [6]

আম

বই

# Not “িব”

EEE 416 (2026) – Project Group C2.04 | Design and Implementation of a Bidirectional Bangla Braille Translation System | 21

# 3.2 Design Methods

## 3.2.12 Braille Input – Case 3: Conjunct Letters (যুার)

## In Braille, a যুার is NOT implemented using a হস, rather it uses a special prefix pattern which indicates if the next two or three letters are conjoined. [5], [6]

## Indicates the next two upcoming letters are conjoined


## Indicates the next three upcoming letters are conjoined

EEE 416 (2026) – Project Group C2.04 | Design and Implementation of a Bidirectional Bangla Braille Translation System | 22

12

# 3.2 Design Methods

## 3.2.12 Braille Input – Case 4: Special Characters (ঋ and ৎ)

ঋ and ৎ requires two consecutive Braille cells. But they follow an interesting pattern. If র

## comes after Dot 5 it becomes ঋ, and if ত comes after Dot 5 it is rendered as ৎ [5], [6]

Dot 5+ র | Dot 5+ ত

## We only have one Braille cell, but we can render these two letters by waiting for two consecutive inputs if the first input is a Dot 5 only

EEE 416 (2026) – Project Group C2.04 | Design and Implementation of a Bidirectional Bangla Braille Translation System | 23

# 3.2 Design Methods

## 3.2.12 Braille Input – Case 5: Conjunct with র (য and র )

Both forms start with the conjunct prefix (Dot 4). Pressing Dot 4 once joins র and য with a
hasanta → য (as in | কায). Pressing Dot 4 twice adds a Zero-Width Joiner (ZWJ) → | র (as in
র াব)


EEE 416 (2026) – Project Group C2.04 | Design and Implementation of a Bidirectional Bangla Braille Translation System | 24

13

# 3.2 Design Methods

## 3.2.12 Braille Input – Case 6: Numbers and Punctuation

A number starts with the number prefix (Dot 4-5); the following cells are read as digits until a space or a new line. Punctuation marks have their own cells.


## Dots 2-5-6 mean দািঁড় (।) in text but a decimal point (.) inside a number: 4-5, 1-4, 2-5-6, 1 → ৩.১. A space ends number mode, so space + 2-5-6 after a number gives ১।

EEE 416 (2026) – Project Group C2.04 | Design and Implementation of a Bidirectional Bangla Braille Translation System | 25

3.2 Design Methods; Bangla text received over Wi-Fi; UTF-8 decode readUTF8(); Rule dispatch translateBangla(); Cell buffer brailleBuffer[ ]; nothing is re-translated.

EEE 416 (2026) – Project Group C2.04 | Design and Implementation of a Bidirectional Bangla Braille Translation System | 26

## 3.2.13 Braille Output – Translation Pipeline

### showBrailleCell() drives the six solenoids — one cell at a time

The whole message is translated once. Afterwards, the Next / Previous buttons only move currentCell —

14

# 3.2 Design Methods

EEE 416 (2026) – Project Group C2.04 | Design and Implementation of a Bidirectional Bangla Braille Translation System | 27

## 3.2.13 Braille Output – Step 1: Decoding the Bangla Text

## One Bangla letter = three bytes

E0 | A6 | 95

U+0995 = ক

## The decoded Bangla character is then matched with the look up table to store

the Braille pattern.

appendPattern(1345); digits 1, 3, 4, 5; → bits 0, 2, 3, 4; mask = 00011101; ↑ currentCell = 0; brailleLength = 5; Bit 0 = dot 1 … bit 5 = dot 6.; Digit order does not matter — the mask is just a set of bits.; 3.2 Design Methods

## 3.2.13 Braille Output – Step 2: Storing a Braille Cell

## brailleBuffer[ ] — one byte per cell, 512 cells maximum

EEE 416 (2026) – Project Group C2.04 | Design and Implementation of a Bidirectional Bangla Braille Translation System | 28

15

## 3.2.13 Braille Output – Step 3: Rule Dispatch Order

### 1. Space or newline → one blank cell (exits number mode)

### 5. “.” inside a number → decimal point (Dots 2-5-6)

### 4. Digit → number sign (Dots 4-5) before the first digit, then digit cells

### 2. and → a single special sign

### 3. Any other cluster → prefix cell + each consonant (য → Dot 4 + র + য)

### 6. Consonant, kar, punctuation → direct table lookup

### 7. Independent vowel → অ inserted when needed

### 8. Chandrabindu, anusvara, visarga, ৎ → special signs

Checked top-down.

The first rule that matches wins, consumes its own characters and jumps the index forward.

Specific rules must come before general ones — numbers and conjuncts are checked before letters.

# 3.2 Design Methods

EEE 416 (2026) – Project Group C2.04 | Design and Implementation of a Bidirectional Bangla Braille Translation System | 29

বাংলা → 5 cells; Straight lookup — consonant, kar, consonant. The reader feels one cell at a time and presses Next.; াস → 5 cells; prefix; The dot-4 prefix comes first and warns that the next two letters are joined.; 3.2 Design Methods

## 3.2.13 Braille Output – Putting It Together

EEE 416 (2026) – Project Group C2.04 | Design and Implementation of a Bidirectional Bangla Braille Translation System | 30

16

# 3.3 Design: Circuit Diagram


EEE 416 (2026) – Project Group C2.04 | Design and Implementation of a Bidirectional Bangla Braille Translation System | 31

The Schematic is designed using - Cirkit Designer [14]

Fig. Complete System Diagram

# 3.4 Design: Circuit Implementation on Veroboard

Front; Back

EEE 416 (2026) – Project Group C2.04 | Design and Implementation of a Bidirectional Bangla Braille Translation System | 32
Fig. OLED Connection | Fig. Speaker Connection

Fig. PCF8575 Connection
Fig. Solenoid Setup

Fig. Solenoid Driving Circuit

17

# 3.5 Design: CAD Model


EEE 416 (2026) – Project Group C2.04 | Design and Implementation of a Bidirectional Bangla Braille Translation System | 33

## 3D Chassis Model

The 3D model design was outsourced under our design guidelines.

# 4. Implementation: Demonstration


EEE 416 (2026) – Project Group C2.04 | Design and Implementation of a Bidirectional Bangla Braille Translation System | 34
Braille to Bangla | Bangla to Braille

18

4.1 Implementation: Photo Gallery; Fig. Bangla Character ক; Fig. Startup Message; Fig. Example Entry; Fig. Final Setup

EEE 416 (2026) – Project Group C2.04 | Design and Implementation of a Bidirectional Bangla Braille Translation System | 35
Fig. Corresponding Input Pattern for ক | Fig. Corresponding Output Pattern for ক

# 5. Design Analysis and Evaluation

# ◦5.1 Novelty ◦5.2 Design Considerations ◦5.3 Investigations ◦5.4 Limitations of Tools ◦5.5 Impact Assessment ◦5.6 Sustainability and Environmental Impact Evaluation ◦5.7 Ethical Issues

EEE 416 (2026) – Project Group C2.04 | Design and Implementation of a Bidirectional Bangla Braille Translation System | 36

19

# 5.1 Novelty

EEE 416 (2026) – Project Group C2.04 | Design and Implementation of a Bidirectional Bangla Braille Translation System | 37

### •Two-Way Communication: Bangla ↔ Braille in one device (earlier works

are one-way [7], [8], [9]) •All-in-One System: Braille input + physical Braille output •Multi-Modal Feedback: Tactile + Visual + Audio

### •Web-Based Input: Bangla text input without a separate app

### •Bangla Support: Handles Kar, Hoshonto, digits, punctuation & conjuncts

•Refreshable Braille: 6-solenoid physical Braille cell •Smart Mode Switching: READ/WRITE content is preserved

# 5.2 Design Considerations

### Public Health and Safety

- Low-voltage control electronics are used. ◦ Solenoids require proper driver and protection circuits. ◦ Electrical connections are insulated from the user.

### Environmental Considerations

- The system uses reusable electronic modules. ◦ Individual modules can be replaced instead of replacing the entire device. ◦ Future versions can reduce solenoid power consumption.

### Cultural and Societal Needs

- The system is specifically designed for Bangla language communication for visually impaired people. ◦ Bangla text is used in the display and webpage. ◦ Bangla audio feedback improves accessibility. ◦ The project addresses the communication needs of Bangla speaking Braille users.
EEE 416 (2026) – Project Group C2.04 | Design and Implementation of a Bidirectional Bangla Braille Translation System | 38

20

# 5.3 Investigations

EEE 416 (2026) – Project Group C2.04 | Design and Implementation of a Bidirectional Bangla Braille Translation System | 39

### What we investigated and the design decision each finding led to -

### 5.3.1 Public health and safety

- Coil heating: 2 s ON / 1 s OFF drive cuts average coil power to 67 %
- Voltage spikes: 1N5822
flyback diode on every coil protects the MOSFET and
ESP32
- Power-up: 10 kΩ pull-downs keep all dots down during boot

5.3.2 Environment • Energy: ≈ 36 W worst case,

drawn only while all solenoids are raised

- Repairability: modular boards — replace one part, not the device
- E-waste: mains supply &
rechargeable LiPo battery, no disposable batteries

### 5.3.3 Cultural and societal needs

- Bangla Braille: kar, silent অ, conjuncts, ঋ / ৎ and numbers

follow the standard [5], [6] • Bangla display: BanglaText +

Kalpurush font on the OLED [11] • Audio: 104 Bangla clips speak

every letter and command [13] • Access: web page on any phone;

warnings in Bangla

# 5.4 Limitations of Tools

EEE 416 (2026) – Project Group C2.04 | Design and Implementation of a Bidirectional Bangla Braille Translation System | 40

•Single Braille Cell: Long text must be read one character at a time. •Limited Memory: Only a fixed amount of Braille data can be stored. •Pre-recorded Audio: Audio comes from MP3 files on the SD card [13]. •No Automatic Voice: Audio for a complete word or sentence cannot be processed. •Local Wi-Fi: The webpage works only through the ESP32 network. •Limited Characters: Some punctuation marks and complex symbols are not implemented for simplicity and

to avoid conflicts. •High Power: Solenoids require more current. •Slow & Heating: Solenoids are slower and may heat up with long use.

21

# 5.5 Impact Assessment

Societal and Cultural Impact ◦ Can improve communication between Bangla Braille users and non-Braille users. ◦ May assist in Bangla Braille education and practice. ◦ Can be used as a typing device for visually impaired people.

Health and Safety Impact ◦ Tactile output can reduce dependence on visual interfaces. ◦ Solenoid movement, heating and electrical current are controlled safely.

## Legal and Privacy Issues

- User entered text is processed locally by the ESP32 web server. ◦ The prototype should be presented as an educational assistive system, not as a certified

commercial accessibility device.

EEE 416 (2026) – Project Group C2.04 | Design and Implementation of a Bidirectional Bangla Braille Translation System | 41

# 5.6 Sustainability Evaluation

EEE 416 (2026) – Project Group C2.04 | Design and Implementation of a Bidirectional Bangla Braille Translation System | 42

•ESP32 and other modules are reusable and widely available.

•Modular construction allows damaged parts to be replaced separately.

•Local processing reduces dependence on external servers or cloud services.

•The web interface does not require installation of an additional application.

22

# 5.7 Ethical Issues

EEE 416 (2026) – Project Group C2.04 | Design and Implementation of a Bidirectional Bangla Braille Translation System | 43
- Standard rule maintained: The device follows the Bangla Braille code [5], [6] instead of a private code; any deviation forced by the single cell design is documented. • Honest claims: Presented as an educational prototype, not a certified medical or accessibility

product. It still needs testing with blind users and Braille teachers. • Privacy: Text is processed only on the ESP32; nothing is sent to the internet or stored. • Safety: Coil current is switched through MOSFETs with flyback diodes, and the ON/OFF cycle limits

heating of parts the user touches. • Credit: Open source libraries (U8g2 [12], BanglaText [11], DFRobot DFPlayer [10]), the Bengali-

Alphabet audio clips [13] and all papers used are cited in the references. • Team ethics: work was shared openly and every member's contribution is stated in Section 6.

# 6.1 Individual Contribution of Each Member

EEE 416 (2026) – Project Group C2.04 | Design and Implementation of a Bidirectional Bangla Braille Translation System | 44
Member | Student ID | Main contribution
Mushfiqur Rahman | 2106181 | Bangla text processing(Conjunct, Punctuation, Number, Special character), Text to Braille processing, Circuit soldering, Total system integration, Documentation
Chayan Paul | 2106182 | Braille to audio processing, DFPlayer Bug fix, Solenoid circuit operation, Logistics, System integration, Documentation
Shamin Yeaser | 2106183 | Bangla text processing(Kar, Conjunct), DFPlayer testing, Display setup for Bangla text, System integration, Logistics, Documentation
Kayes Sami Malitha | 2106184 | Webpage hosting, Circuit soldering, audio file conversion, Logistics, System integration, Documentation

# 6. Reflection on Individual and Team Work

23

# 6.2 Mode of Teamwork and Diversity

EEE 416 (2026) – Project Group C2.04 | Design and Implementation of a Bidirectional Bangla Braille Translation System | 45

### - Divide by subsystem: The system was built part by part, where the team members worked

cooperatively. • Test alone, then integrate: Each part was proven on a breadboard first, then merged into one

firmware. • Regular reviews: Progress was checked against the proposed system and the remaining work was

reassigned. • Diversity: members brought different strengths — firmware, circuit building, web design and

documentation — and decisions were made together.

# 6. Reflection on Individual and Team Work

# 7. Communication to External Stakeholders

EEE 416 (2026) – Project Group C2.04 | Design and Implementation of a Bidirectional Bangla Braille Translation System | 46
Channel | Link / details
GitHub repository | https://github.com/intmushfiq/Bidirectional-Bangla-Braille-Device
YouTube demonstration video | https://youtu.be/4rY5ggd-0BE

24

EEE 416 (2026) – Project Group C2.04 | Design and Implementation of a Bidirectional Bangla Braille Translation System | 47

# 8. Project Management and Cost Analysis

## 8.1 Bill of materials

Item | Qty | Unit (৳) | Total (৳)
ESP32 DevKit (30-pin) | 1 | 480 | 480
SH1106 OLED 1.3" (I²C) | 1 | 600 | 600
PCF8575 I/O expander module | 1 | 350 | 350
DFPlayer Mini | 1 | 240 | 240
32 GB microSD | 1 | 650 | 650
4 Ω 3 W speaker | 1 | 280 | 280
5 V push-pull solenoid | 6 | 250 | 1500
IRLB8721 MOSFET | 6 | 150 | 900
1N5819 diode, resistors | — | — | 50
Push buttons (6 latching, 3 other) | 9 | 10 | 90
LiPo Battery + Buck Converter | 1 | 2200 | 2200
Veroboard, wires, misc. | — | — | 500
Enclosure (3D printing) | 1 | 3000 | 3000
Prototype total | | | 10,840

### 8.2 Per-unit cost

Prototype: ≈ ৳ 10,800
Mass-produced: ≈ ৳ 6,500

Custom PCB instead of modules and breadboards, bulk solenoids, an injection-moulded enclosure and a smaller 5 V supply sized for one cell cut about 35–40 %.

# 9. Future Work

EEE 416 (2026) – Project Group C2.04 | Design and Implementation of a Bidirectional Bangla Braille Translation System | 48
- Add multiple Braille cells for faster reading.
- Design PCB layout for a compact device.
- Add Bangla text-to-speech instead of recorded audio.
- Support more Bangla punctuation marks and symbols.
- Add English or other language processing capability.
- Improve the Braille cell design.
- Reduce power use and heating.
- Test the device with visually impaired users and Braille teachers.

25
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

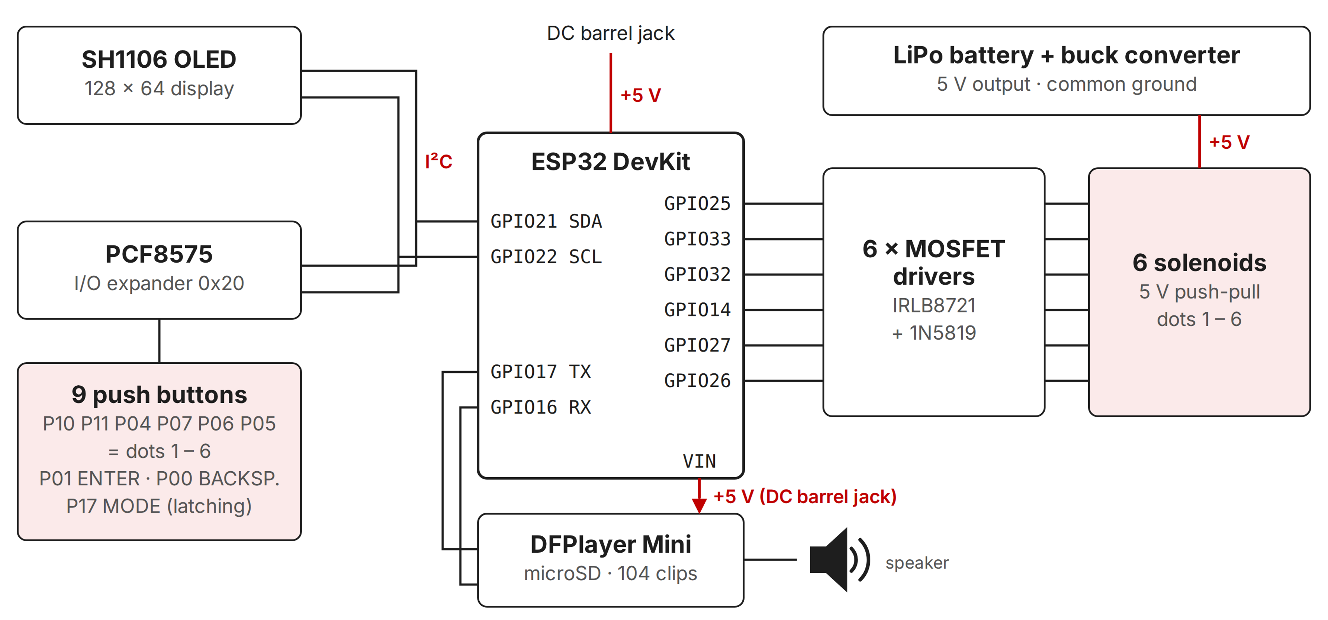
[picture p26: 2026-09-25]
Schematic/Pin Diagram.png

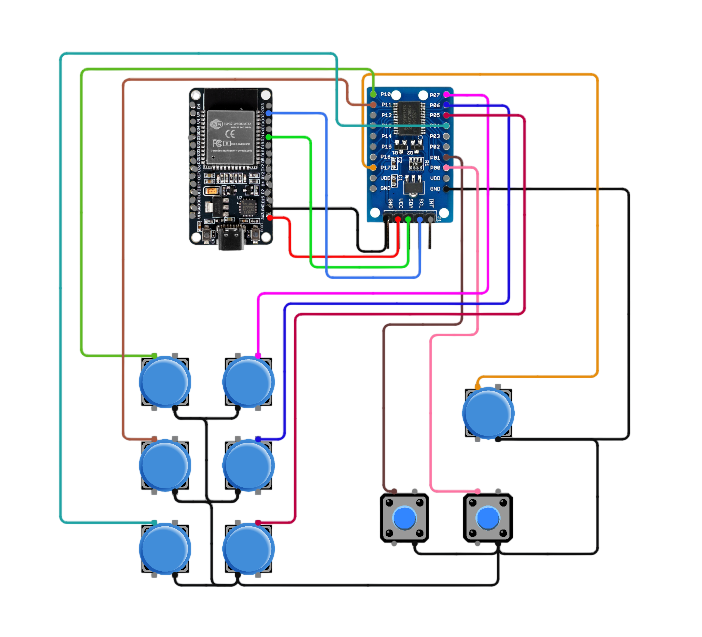
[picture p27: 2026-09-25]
Schematic/Pushbutton_Schematic.png

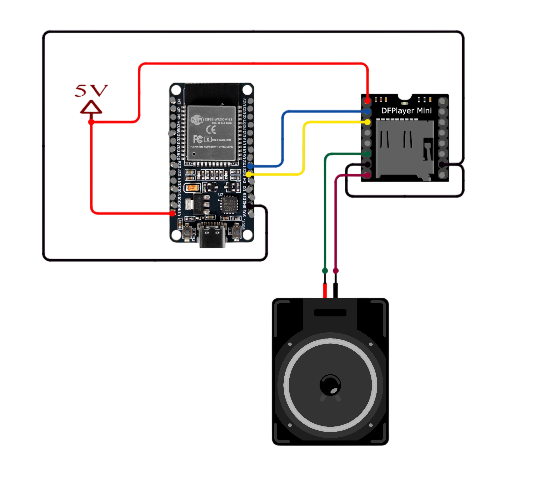
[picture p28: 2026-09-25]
Schematic/Speaker_Schematic.png

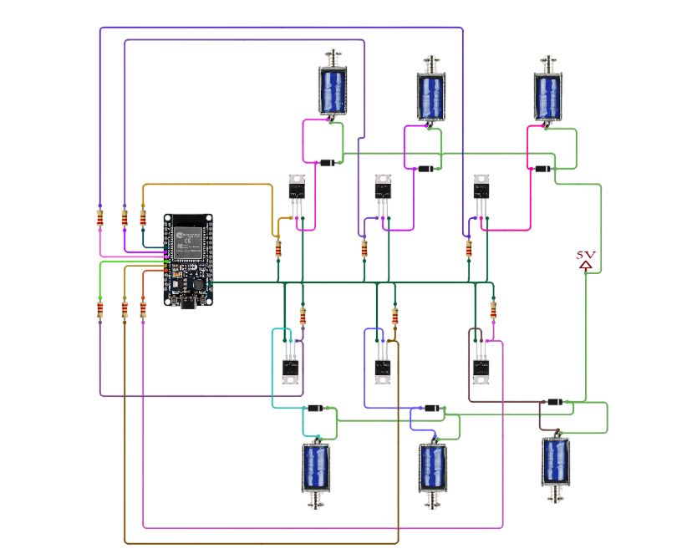
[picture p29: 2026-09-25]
Schematic/Solenoid_Schematic.png

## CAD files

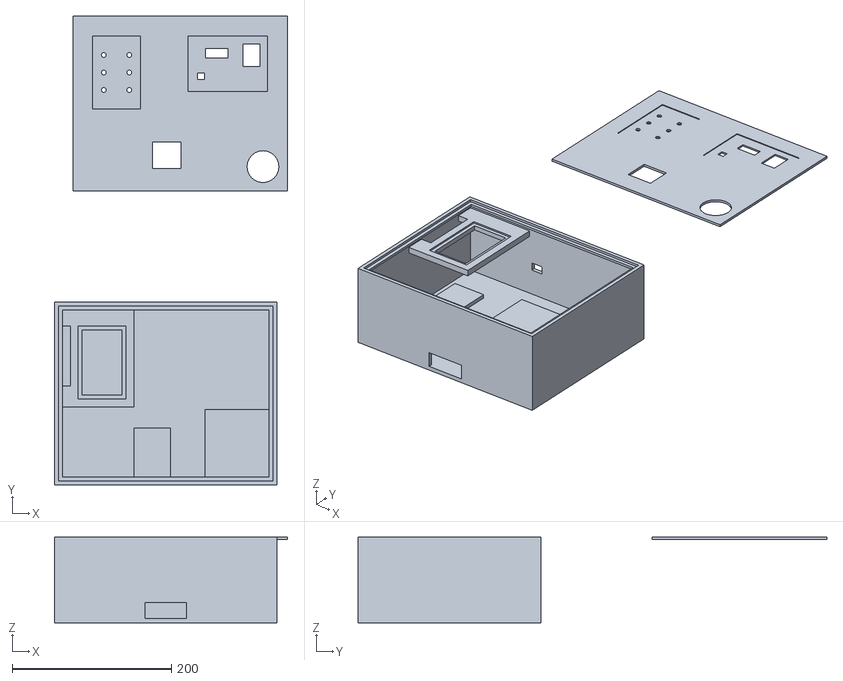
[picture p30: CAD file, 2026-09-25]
3D Model/Model.stl
293.1 x 589.3 x 108.0

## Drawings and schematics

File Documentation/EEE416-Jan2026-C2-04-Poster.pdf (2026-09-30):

# Design and Implementation of a Bidirectional Bangla Braille Translation System

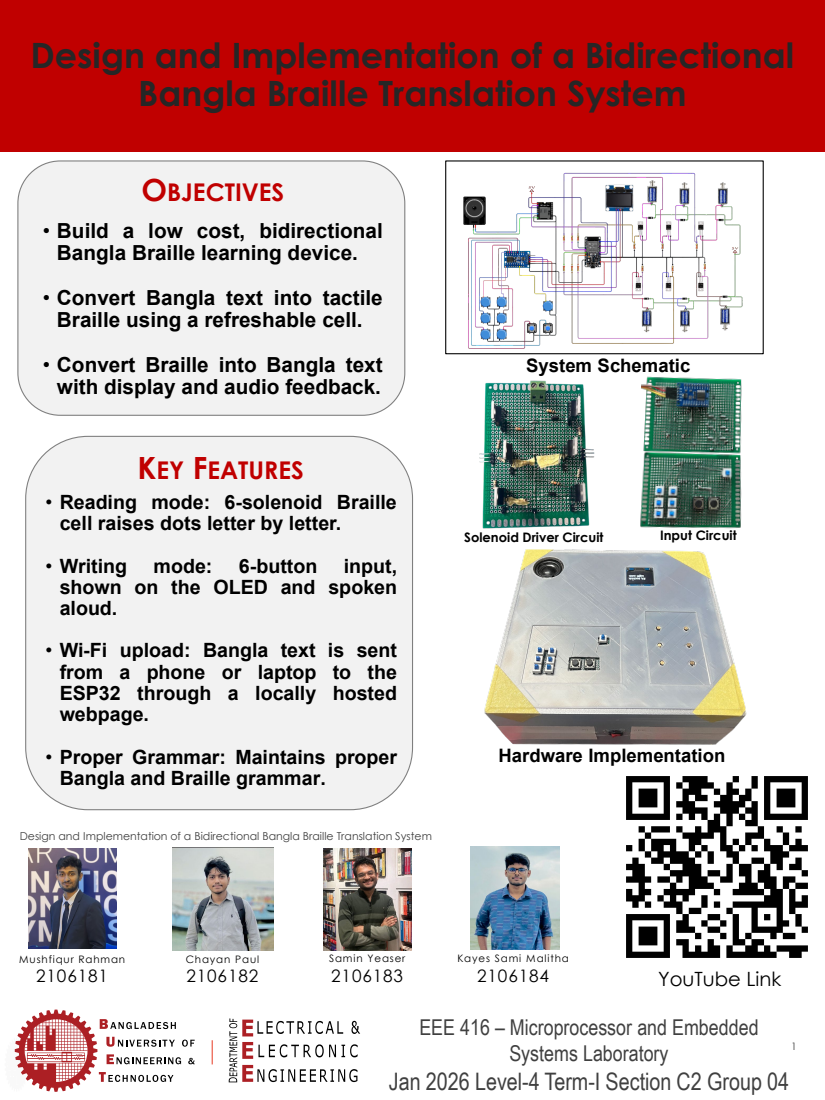
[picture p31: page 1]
Chayan Paul 2106182; Mushfiqur Rahman 2106181; OBJECTIVES; KEY FEATURES; YouTube Link; System Schematic; Hardware Implementation; Input Circuit

• Build a low cost, bidirectional
Bangla Braille learning device.
• Convert Bangla text into tactile
Braille using a refreshable cell.
• Convert Braille into Bangla text
with display and audio feedback.

• Reading mode: 6-solenoid Braille
cell raises dots letter by letter.
• Writing mode: 6-button input,
shown on the OLED and spoken
aloud.
• Wi-Fi upload: Bangla text is sent
from a phone or laptop to the
ESP32 through a locally hosted
webpage.
• Proper Grammar: Maintains proper
Bangla and Braille grammar.

Solenoid Driver Circuit

Design and Implementation of a Bidirectional Bangla Braille Translation System

Samin Yeaser
EEE 416 – Microprocessor and Embedded
Systems Laboratory

Kayes Sami Malitha

Jan 2026 Level-4 Term-I Section C2 Group 04

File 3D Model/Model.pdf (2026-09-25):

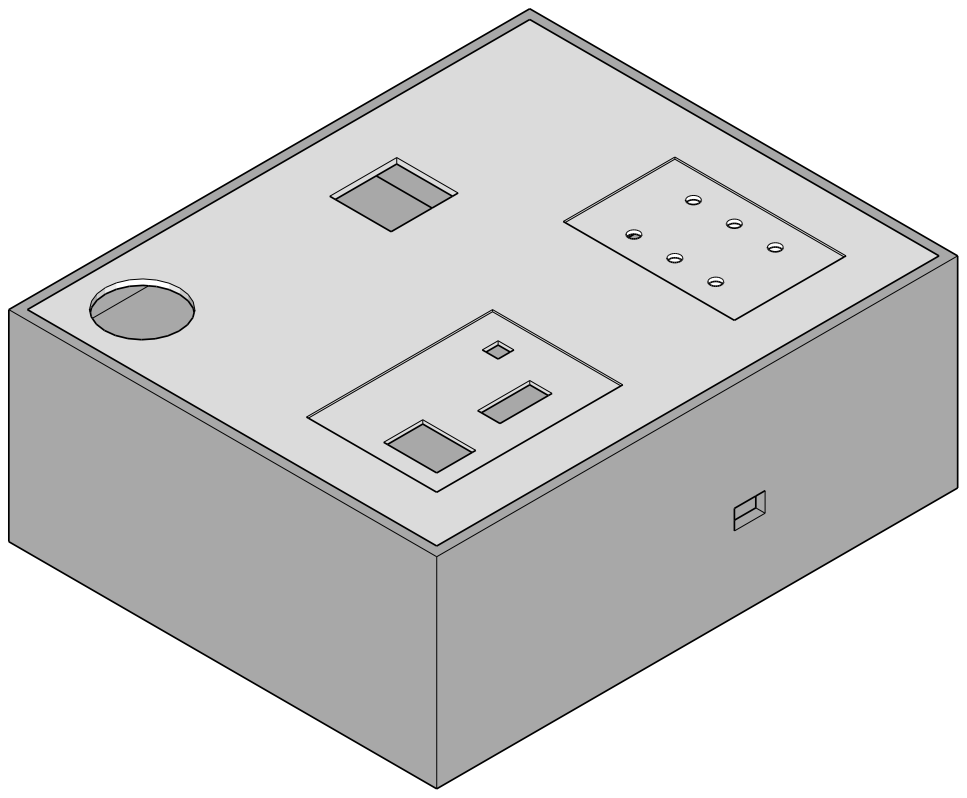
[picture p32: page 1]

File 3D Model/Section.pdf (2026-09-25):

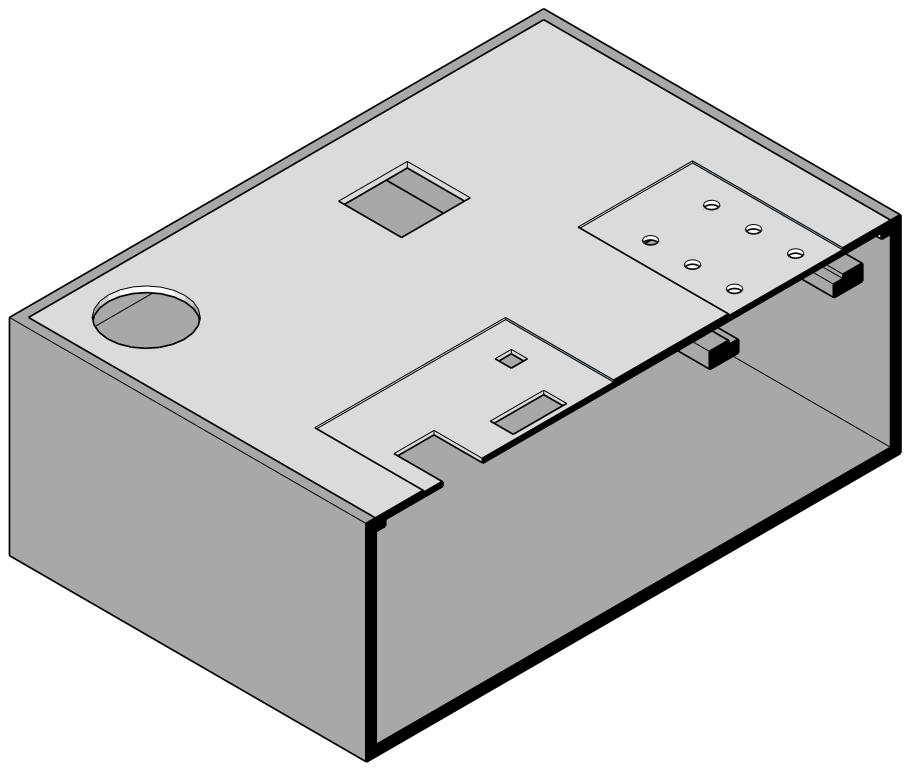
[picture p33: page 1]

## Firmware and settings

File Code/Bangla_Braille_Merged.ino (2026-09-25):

// =====================================================
// Bangla Braille Device 
// =====================================================

// Files needed in the same sketch folder: speaker.h, WebPage.h, Kalpurush_20pt.h

#include <Arduino.h>
#include <BanglaText.h>
#include "Kalpurush_20pt.h"
#include <U8g2lib.h>
#include <Wire.h>
#include <WiFi.h>
#include <WebServer.h>
#include <PCF8575.h>
#include "speaker.h"                                   


// =====================================================
// OLED
// =====================================================
U8G2_SH1106_128X64_NONAME_F_HW_I2C u8g2(
    U8G2_R2,
    /* reset=*/ U8X8_PIN_NONE
);


// =====================================================
// PCF8575 I/O EXPANDER
// =====================================================
PCF8575 pcf(&Wire, 0x20);


// =====================================================
// Wi-Fi Access Point
// =====================================================
const char* ssid = "Braille_Bangla";
const char* password = "123456789";

WebServer server(80);

// =====================================================
// Webpage header file
// =====================================================
#include "WebPage.h"


// =====================================================
// BANGLA FONT  (shared by both modes)
// =====================================================
BTfont font;
BanglaTextRenderer *textRenderer;

// =====================================================
// MODE SELECTION                                
// =====================================================

#define MODE_BIT 15          // P17               

#define MODE_DEBOUNCE 50     // ms

// false = WRITE mode (Braille -> Bangla keyboard)
// true  = READ  mode (Bangla -> Braille solenoids)
bool readMode = false;                          

// =====================================================
// POWER-UP TITLE                                
// =====================================================
#define DEVICE_TITLE "বাংলা ব্রেইল অনুবাদক যন্ত্র"

// false until something has been written in WRITE mode
bool writeStarted = false;                       

// READ mode text renderer (defined in the READ section)
void displayReadText(String text);               


// =====================================================
//
//          WRITE MODE  (Braille -> Bangla)
//
// =====================================================

// =====================================================
// PINS  (PCF8575 bit indices)
// =====================================================
#define DOT1_BIT 8      // P10
#define DOT2_BIT 9      // P11
#define DOT3_BIT 4      // P04
#define DOT4_BIT 7      // P07
#define DOT5_BIT 6      // P06
#define DOT6_BIT 5      // P05

#define ENTER_BIT 1     // P01
#define BACKSPACE_BIT 0 // P00

#define DEBOUNCE_DELAY 40

#define ENTER_REPEAT_GUARD 180
#define ENTER_HOLD_TIME 2000


// =====================================================
// CONTROL PATTERNS
// =====================================================
#define PATTERN_SPACE          0     // no dots
#define PATTERN_CONJUNCT2      8     // (4)
#define PATTERN_SPECIAL_VOWEL  16    // (5)
#define PATTERN_NUMBER         24    // (45)
#define PATTERN_CONJUNCT3      40    // (46)


// =====================================================
// MULTI-CODE-POINT LETTERS
// =====================================================
#define BN_HASANTA "\u09CD"
#define BN_NUKTA   "\u09BC"
#define BN_ZWJ     "\u200D"              // zero width joiner
#define BN_RA      "\u09B0"              // র
#define BN_RRA     "\u09A1\u09BC"        // ড়
#define BN_RHA     "\u09A2\u09BC"        // ঢ়
#define BN_YYA     "\u09AF\u09BC"        // য়
#define BN_KSSA    "\u0995\u09CD\u09B7"  // ক্ষ
#define BN_JNYA    "\u099C\u09CD\u099E"  // জ্ঞ


// =====================================================
// DISPLAY LAYOUT
// =====================================================
#define LINE_HEIGHT 21
#define MAX_LINES 3

// Usable width for text, in pixels.
// A line wider than this wraps automatically.
#define DISPLAY_WIDTH 128
#define MAX_WRAPPED_LINES 40


// =====================================================
// OUTPUT TEXT
// =====================================================

String outputText = "";


// =====================================================
// SPECIAL অ STATE
// =====================================================

bool suppressedA = false;


// =====================================================
// SPECIAL ঋ / ৎ PREFIX STATE
// =====================================================
bool pendingSpecialVowel = false;


// =====================================================
// NUMBER MODE STATE
// =====================================================
bool numberMode = false;
size_t numberStartLength = 0;

// True right after a SPACE ended number mode, until the
// next action.
bool numberEndedBySpace = false;


// =====================================================
// CONJUNCT STATE
// =====================================================
uint8_t pendingConjunct = 0;

String conjunctBuffer = "";

bool conjunctZWJ = false;


// =====================================================
// BUTTON SNAPSHOT
// =====================================================
uint16_t buttonState = 0xFFFF;


// =====================================================
// ENTER ACTION
// =====================================================
enum EnterAction
{
    ENTER_ACTION_NONE,
    ENTER_ACTION_NEWLINE,
    ENTER_ACTION_SPACE,
    ENTER_ACTION_PATTERN
};


// =====================================================
// FUNCTION DECLARATIONS (WRITE mode)
// =====================================================

void draw_pixel(int16_t x, int16_t y);

uint16_t readExpander();
bool isDown(uint8_t bit);

uint8_t readBraille();
void printDots(uint8_t pattern);

String brailleToBangla(uint8_t pattern);
String brailleNumberToString(uint8_t pattern);
bool isPunctuation(const String &text);

uint16_t textWidth(const String &text);
uint32_t codePointAt(const String &text, int i, int &len);
int nextClusterEnd(const String &text, int start);
uint8_t buildDisplayLines(const String &text, String *lines, uint8_t maxLines);
void renderLines(const String &text);
void displayText();
void displayConjunctPreview();
void addNewLine();

bool isBanglaVowel(const String &text);
bool isBanglaConsonant(const String &text);

String vowelToKar(const String &vowel);

int prevCodePointStart(const String &text, int end);
int lastUnitStart(const String &text);
int nextUnitEnd(const String &text, int start);
uint8_t countUnits(const String &text);

String getLastCharacter(const String &text);
void removeLastCharacter();

bool isWordStart();

void processCharacter(const String &character);
void processNormalCharacter(const String &character);
void processNumber(uint8_t pattern);

void processA();
void addVowel(const String &vowel);
void addNonVowel(const String &character);

void startNumberMode();
void endNumberMode();

void startConjunct(uint8_t count);
void processConjunctCharacter(const String &character);
void finishConjunct();
void cancelConjunct();

void backspaceText();
void clearAllText();
void handleBackspaceButton();

EnterAction handleEnterButton(uint8_t &pattern);

void writeModeLoop();                             


// =====================================================
// PIXEL CALLBACK (WRITE mode)
// =====================================================

// Vertical offset used when rendering multiple display lines.
int16_t displayLineOffset = 0;

void draw_pixel(int16_t x, int16_t y)
{
    u8g2.drawPixel(y, 17 - x + displayLineOffset);
}


// =====================================================
// READ EXPANDER
// =====================================================
uint16_t readExpander()
{
    PCF8575::DigitalInput in = pcf.digitalReadAll();

    uint16_t w = 0;

    if (in.p0)  w |= (1 << 0);
    if (in.p1)  w |= (1 << 1);
    if (in.p2)  w |= (1 << 2);
    if (in.p3)  w |= (1 << 3);
    if (in.p4)  w |= (1 << 4);
    if (in.p5)  w |= (1 << 5);
    if (in.p6)  w |= (1 << 6);
    if (in.p7)  w |= (1 << 7);

    if (in.p8)  w |= (1 << 8);    // silkscreen P10
    if (in.p9)  w |= (1 << 9);    // silkscreen P11
    if (in.p10) w |= (1 << 10);   // silkscreen P12
    if (in.p11) w |= (1 << 11);   // silkscreen P13
    if (in.p12) w |= (1 << 12);   // silkscreen P14
    if (in.p13) w |= (1 << 13);   // silkscreen P15
    if (in.p14) w |= (1 << 14);   // silkscreen P16
    if (in.p15) w |= (1 << 15);   // silkscreen P17

    return w;
}


// =====================================================
// BUTTON TEST
// =====================================================
bool isDown(uint8_t bit)
{
    return !(buttonState & (1 << bit));
}


// =====================================================
// READ BRAILLE
// =====================================================

uint8_t readBraille()
{
    uint8_t pattern = 0;

    if (isDown(DOT1_BIT)) pattern |= (1 << 0);
    if (isDown(DOT2_BIT)) pattern |= (1 << 1);
    if (isDown(DOT3_BIT)) pattern |= (1 << 2);
    if (isDown(DOT4_BIT)) pattern |= (1 << 3);
    if (isDown(DOT5_BIT)) pattern |= (1 << 4);
    if (isDown(DOT6_BIT)) pattern |= (1 << 5);

    return pattern;
}


// =====================================================
// PRINT DOTS
// =====================================================

void printDots(uint8_t pattern)
{
    Serial.print("Dots: ");

    bool any = false;

    for (int i = 0; i < 6; i++)
    {
        if (pattern & (1 << i))
        {
            Serial.print(i + 1);
            Serial.print(" ");
            any = true;
        }
    }

    if (!any)
        Serial.print("NONE");

    Serial.println();
}


// =====================================================
// BRAILLE -> BANGLA
// =====================================================
String brailleToBangla(uint8_t p)
{
    // -----------------------------------------------------
    // PUNCTUATION
    // -----------------------------------------------------
    if (p == 2)  return ",";       // 2
    if (p == 6)  return ";";       // 23
    if (p == 50) return "।";       // 256
    if (p == 38) return "?";       // 236
    if (p == 22) return "!";       // 235
    if (p == 36) return "-";       // 36


    // -----------------------------------------------------
    // VOWELS
    // -----------------------------------------------------

    if (p == 1)  return "অ";       // 1
    if (p == 28) return "আ";       // 345
    if (p == 10) return "ই";       // 24
    if (p == 20) return "ঈ";       // 35
    if (p == 37) return "উ";       // 136
    if (p == 51) return "ঊ";       // 1256
    if (p == 17) return "এ";       // 15
    if (p == 12) return "ঐ";       // 34
    if (p == 21) return "ও";       // 135
    if (p == 42) return "ঔ";       // 246


    // -----------------------------------------------------
    // CONSONANTS
    // -----------------------------------------------------

    if (p == 5)  return "ক";       // 13
    if (p == 45) return "খ";       // 1346
    if (p == 27) return "গ";       // 1245
    if (p == 35) return "ঘ";       // 126
    if (p == 44) return "ঙ";       // 346

    if (p == 9)  return "চ";       // 14
    if (p == 33) return "ছ";       // 16
    if (p == 26) return "জ";       // 245
    if (p == 53) return "ঝ";       // 1356
    if (p == 18) return "ঞ";       // 25

    if (p == 62) return "ট";       // 23456
    if (p == 58) return "ঠ";       // 2456
    if (p == 43) return "ড";       // 1246
    if (p == 63) return "ঢ";       // 123456
    if (p == 60) return "ণ";       // 3456

    if (p == 30) return "ত";       // 2345
    if (p == 57) return "থ";       // 1456
    if (p == 25) return "দ";       // 145
    if (p == 46) return "ধ";       // 2346
    if (p == 29) return "ন";       // 1345

    if (p == 15) return "প";       // 1234
    if (p == 11) return "ফ";       // 124
    if (p == 3)  return "ব";       // 12
    if (p == 39) return "ভ";       // 1236
    if (p == 13) return "ম";       // 134

    if (p == 61) return "য";       // 13456
    if (p == 23) return "র";       // 1235
    if (p == 7)  return "ল";       // 123

    if (p == 41) return "শ";       // 146
    if (p == 47) return "ষ";       // 12346
    if (p == 14) return "স";       // 234
    if (p == 19) return "হ";       // 125

    if (p == 59) return BN_RRA;    // 12456  ড়
    if (p == 55) return BN_RHA;    // 12356  ঢ়
    if (p == 34) return BN_YYA;    // 26     য়


    // -----------------------------------------------------
    // SPECIAL DIRECT CONJUNCT CHARACTERS
    // -----------------------------------------------------

    if (p == 31) return BN_KSSA;   // 12345  ক্ষ
    if (p == 49) return BN_JNYA;   // 156    জ্ঞ


    // -----------------------------------------------------
    // SPECIAL SIGNS
    // -----------------------------------------------------

    if (p == 48) return "ং";       // 56
    if (p == 32) return "ঃ";       // 6
    if (p == 4)  return "ঁ";       // 3


    return "";
}


// =====================================================
// BRAILLE NUMBER DIGIT
// =====================================================

// Number prefix: 45
String brailleNumberToString(uint8_t p)
{
    if (p == 1)  return "১";       // 1
    if (p == 3)  return "২";       // 12
    if (p == 9)  return "৩";       // 14
    if (p == 25) return "৪";       // 145
    if (p == 17) return "৫";       // 15
    if (p == 11) return "৬";       // 124
    if (p == 27) return "৭";       // 1245
    if (p == 19) return "৮";       // 125
    if (p == 10) return "৯";       // 24
    if (p == 26) return "০";       // 245

    return "";
}


// =====================================================
// PUNCTUATION CHECK (WRITE mode, String version)
// =====================================================

bool isPunctuation(const String &text)
{
    return (
        text == "," ||
        text == ";" ||
        text == "।" ||
        text == "?" ||
        text == "!" ||
        text == "-"
    );
}


// =====================================================
// LETTER UNITS (UTF-8)
// =====================================================

// Start index of the UTF-8 code point that ends at 'end'.
int prevCodePointStart(const String &text, int end)
{
    int i = end - 1;

    while (i > 0 && ((uint8_t)text[i] & 0xC0) == 0x80)
        i--;

    return i;
}


// Start index of the last letter unit in text.
int lastUnitStart(const String &text)
{
    int len = text.length();

    if (len == 0)
        return 0;

    if (text.endsWith(BN_KSSA) || text.endsWith(BN_JNYA))
    {
        int s = len - 9;

        bool partOfLonger =
            s >= 3 && text.substring(s - 3, s) == BN_HASANTA;

        if (!partOfLonger)
            return s;
    }

    int i = prevCodePointStart(text, len);

    // Nukta belongs to the letter before it.
    if (i > 0 && text.substring(i) == BN_NUKTA)
        i = prevCodePointStart(text, i);

    // A hasanta after ZWJ (from র‍্য) is removed together
    if (
        i >= 3 &&
        text.substring(i) == BN_HASANTA &&
        text.substring(i - 3, i) == BN_ZWJ
    )
        i -= 3;

    return i;
}

int nextUnitEnd(const String &text, int start)
{
    int n = text.length();

    int i = start + 1;

    while (i < n && ((uint8_t)text[i] & 0xC0) == 0x80)
        i++;

    if (i < n && text.substring(i, i + 3) == BN_NUKTA)
        i += 3;

    return i;
}


// ড় counts as ONE consonant).
uint8_t countUnits(const String &text)
{
    uint8_t count = 0;

    for (int i = 0; i < (int)text.length(); )
    {
        i = nextUnitEnd(text, i);
        count++;
    }

    return count;
}


// =====================================================
// LAST CHARACTER
// =====================================================

String getLastCharacter(const String &text)
{
    if (text.length() == 0)
        return "";

    return text.substring(lastUnitStart(text));
}


// =====================================================
// REMOVE LAST CHARACTER
// =====================================================

void removeLastCharacter()
{
    if (outputText.length() == 0)
        return;

    outputText.remove(lastUnitStart(outputText));


    // Dangling reph cleanup.

    if (outputText.endsWith(BN_RA BN_ZWJ BN_HASANTA))
    {
        // remove ZWJ (3 bytes) + hasanta (3 bytes)
        outputText.remove(outputText.length() - 6);
    }
    else if (outputText.endsWith(BN_RA BN_HASANTA))
    {
        // remove hasanta (3 bytes)
        outputText.remove(outputText.length() - 3);
    }
}


// =====================================================
// BANGLA VOWEL CHECK
// =====================================================

bool isBanglaVowel(const String &text)
{
    return (
        text == "অ" ||
        text == "আ" ||
        text == "ই" ||
        text == "ঈ" ||
        text == "উ" ||
        text == "ঊ" ||
        text == "ঋ" ||
        text == "এ" ||
        text == "ঐ" ||
        text == "ও" ||
        text == "ঔ"
    );
}


// =====================================================
// BANGLA CONSONANT CHECK
// =====================================================

bool isBanglaConsonant(const String &text)
{
    return (
        text == "ক" ||
        text == "খ" ||
        text == "গ" ||
        text == "ঘ" ||
        text == "ঙ" ||

        text == "চ" ||
        text == "ছ" ||
        text == "জ" ||
        text == "ঝ" ||
        text == "ঞ" ||

        text == "ট" ||
        text == "ঠ" ||
        text == "ড" ||
        text == "ঢ" ||
        text == "ণ" ||

        text == "ত" ||
        text == "থ" ||
        text == "দ" ||
        text == "ধ" ||
        text == "ন" ||

        text == "প" ||
        text == "ফ" ||
        text == "ব" ||
        text == "ভ" ||
        text == "ম" ||

        text == "য" ||
        text == "র" ||
        text == "ল" ||

        text == "শ" ||
        text == "ষ" ||
        text == "স" ||
        text == "হ" ||

        text == BN_RRA ||
        text == BN_RHA ||
        text == BN_YYA
    );
}


// =====================================================
// VOWEL -> KAR
// =====================================================

String vowelToKar(const String &vowel)
{
    if (vowel == "আ") return "া";
    if (vowel == "ই") return "ি";
    if (vowel == "ঈ") return "ী";
    if (vowel == "উ") return "ু";
    if (vowel == "ঊ") return "ূ";
    if (vowel == "ঋ") return "ৃ";
    if (vowel == "এ") return "ে";
    if (vowel == "ঐ") return "ৈ";
    if (vowel == "ও") return "ো";
    if (vowel == "ঔ") return "ৌ";

    return "";
}


// =====================================================
// WORD START
// =====================================================

bool isWordStart()
{
    if (outputText.length() == 0)
        return true;

    String last = getLastCharacter(outputText);

    // A new word starts after a space, a NEW LINE or any punctuation mark

    return (
        last == " "  ||
        last == "\n" ||
        isPunctuation(last)
    );
}


// =====================================================
// TEXT WIDTH (pixels)
// =====================================================

uint16_t textWidth(const String &text)
{
    if (text.length() == 0)
        return 0;

    BTTextSize size =
        textRenderer->getTextSize(text.c_str());

    if (size.width < 0)
        return 0;

    return size.width;
}


// =====================================================
// UTF-8 CODE POINT AT POSITION
// =====================================================

uint32_t codePointAt(const String &text, int i, int &len)
{
    uint8_t b1 = (uint8_t)text[i];

    if (b1 < 0x80)
    {
        len = 1;
        return b1;
    }

    if ((b1 & 0xE0) == 0xC0 && i + 1 < (int)text.length())
    {
        len = 2;
        return ((uint32_t)(b1 & 0x1F) << 6) |
               ((uint8_t)text[i + 1] & 0x3F);
    }

    if ((b1 & 0xF0) == 0xE0 && i + 2 < (int)text.length())
    {
        len = 3;
        return ((uint32_t)(b1 & 0x0F) << 12) |
               ((uint32_t)((uint8_t)text[i + 1] & 0x3F) << 6) |
               ((uint8_t)text[i + 2] & 0x3F);
    }

    len = 1;
    return b1;
}


// =====================================================
// NEXT CLUSTER END
// =====================================================

bool isAttachedSign(uint32_t c)
{
    return (
        (c >= 0x0981 && c <= 0x0983) ||   // ঁ ং ঃ
        c == 0x09BC ||                    // nukta
        (c >= 0x09BE && c <= 0x09CC) ||   // kar signs
        c == 0x09CD ||                    // hasanta
        c == 0x09D7 ||                    // au length mark
        c == 0x200C ||                    // ZWNJ
        c == 0x200D                       // ZWJ
    );
}
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
void loop()
{
    // =================================================
    // WEB SERVER - always, in both modes  
    // =================================================

    server.handleClient();


    // =================================================
    // READ ALL BUTTONS
    // =================================================

    buttonState = readExpander();


    // =================================================
    // MODE BUTTON (P17)               
    // =================================================

    bool modeChanged = handleModeButton();


    // =================================================
    // ACTIVE MODE                          
    // =================================================

    if (!modeChanged)
    {
        if (readMode)
            readModeLoop();
        else
            writeModeLoop();
    }


    // Send the latest requested sound 

    speakerService();    // <<< SPEAKER


    // Original keyboard loop delay (WRITE mode only)

    if (!readMode)
        delay(5);
}

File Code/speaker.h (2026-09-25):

// =====================================================
// speaker.h
// =====================================================


// SD card layout:  /mp3/0001.mp3 ... /mp3/0104.mp3

#pragma once

#include <Arduino.h>
#include <DFRobotDFPlayerMini.h>


// =====================================================
// CONFIG
// =====================================================

#define DF_RX_PIN        16      // ESP32 RX2  <- DFPlayer TX
#define DF_TX_PIN        17      // ESP32 TX2  -> DFPlayer RX (via 1k)

#define DF_VOLUME        30      // 0 - 30

#define DF_CMD_GAP_MS    40      // minimum time between two commands

#define DF_FINISH_MIN_MS      300
#define DF_FOLLOW_TIMEOUT_MS  2500


// =====================================================
// FEEDBACK TRACKS
// =====================================================

#define TRACK_KSSA          91   // ক্ষ
#define TRACK_JNYA          92   // জ্ঞ
#define TRACK_SPACE         93   // space
#define TRACK_BACKSPACE     94   // backspace
#define TRACK_NEWLINE       95   // new line      (ENTER hold)
#define TRACK_ALL_CLEARED   96   // all cleared   (BACKSPACE hold)
#define TRACK_WRONG         97   // wrong entry   (invalid pattern)
#define TRACK_CONJUNCT_1    98   // conjunct mode 1  (dot 4)
#define TRACK_CONJUNCT_2    99   // conjunct mode 2  (dots 46)
#define TRACK_DOT5         100   // dot 5            (ঋ / ৎ prefix)
#define TRACK_NUMBER_MODE  101   // number mode      (dots 45)

#define TRACK_DECIMAL      102   // দশমিক  (dots 256 inside number mode)
                                 // outside number mode 256 is । -> track 79

#define TRACK_READ_MODE    103   // "Reading mode"  (mode switch / power up)
#define TRACK_WRITE_MODE   104   // "Writing mode"  (mode switch / power up)


struct SpeakEntry
{
    const char *text;
    uint16_t    track;
};

const SpeakEntry SPEAK_TABLE[] =
{
    // ---------------- Vowels (1 - 11) ----------------
    { "অ",   1 }, { "আ",   2 }, { "ই",   3 }, { "ঈ",   4 },
    { "উ",   5 }, { "ঊ",   6 }, { "ঋ",   7 }, { "এ",   8 },
    { "ঐ",   9 }, { "ও",  10 }, { "ঔ",  11 },

    // ---------------- Consonants (12 - 50) ----------------
    { "ক",  12 }, { "খ",  13 }, { "গ",  14 }, { "ঘ",  15 },
    { "ঙ",  16 }, { "চ",  17 }, { "ছ",  18 }, { "জ",  19 },
    { "ঝ",  20 }, { "ঞ",  21 }, { "ট",  22 }, { "ঠ",  23 },
    { "ড",  24 }, { "ঢ",  25 }, { "ণ",  26 }, { "ত",  27 },
    { "থ",  28 }, { "দ",  29 }, { "ধ",  30 }, { "ন",  31 },
    { "প",  32 }, { "ফ",  33 }, { "ব",  34 }, { "ভ",  35 },
    { "ম",  36 }, { "য",  37 }, { "র",  38 }, { "ল",  39 },
    { "শ",  40 }, { "ষ",  41 }, { "স",  42 }, { "হ",  43 },

    { "ড়", 44 },      // ড়
    { "ঢ়", 45 },      // ঢ়
    { "য়", 46 },      // য়

    { "ৎ",  47 }, { "ং",  48 }, { "ঃ",  49 }, { "ঁ",  50 },

    // ---------------- Digits (51 - 60) ----------------
    { "০",  51 }, { "১",  52 }, { "২",  53 }, { "৩",  54 },
    { "৪",  55 }, { "৫",  56 }, { "৬",  57 }, { "৭",  58 },
    { "৮",  59 }, { "৯",  60 },

    // ---------------- Kar signs (61 - 70) ----------------
    { "া",  61 }, { "ি",  62 }, { "ী",  63 }, { "ু",  64 },
    { "ূ",  65 }, { "ে",  66 }, { "ৈ",  67 }, { "ো",  68 },
    { "ৌ",  69 }, { "ৃ",  70 },

    // ---------------- Punctuation ----------------
    { ",",  77 }, { ";",  78 }, { "।",  79 },
    { "?",  80 }, { "!",  81 }, { "-",  85 },

    // ---------------- Direct conjuncts ----------------
    { "ক্ষ", TRACK_KSSA },   // ক্ষ
    { "জ্ঞ", TRACK_JNYA },   // জ্ঞ

    // ---------------- Decimal point (number mode only) ----------------
    { ".", TRACK_DECIMAL },           // দশমিক
};

const uint8_t SPEAK_TABLE_SIZE =
    sizeof(SPEAK_TABLE) / sizeof(SPEAK_TABLE[0]);


// =====================================================
// INTERNAL STATE
// =====================================================

HardwareSerial dfSerial(2);
DFRobotDFPlayerMini dfPlayer;

bool speakerReady = false;

uint16_t      speakPending = 0;      // latest requested track
uint16_t      speakFollow  = 0;      // track to play after the current one
unsigned long speakLastCmd = 0;


// =====================================================
// LOOKUP
// =====================================================

uint16_t trackForText(const String &text)
{
    for (uint8_t i = 0; i < SPEAK_TABLE_SIZE; i++)
    {
        if (text == SPEAK_TABLE[i].text)
            return SPEAK_TABLE[i].track;
    }

    return 0;
}


// =====================================================
// REQUEST A SOUND
// =====================================================

void speakTrack(uint16_t track)
{
    if (!speakerReady || track == 0)
        return;

    speakPending = track;

    // A new sound cancels anything that was queued.
    speakFollow = 0;
}


void speakTrackNext(uint16_t track)
{
    if (!speakerReady || track == 0)
        return;

    speakFollow = track;
}


void speakText(const String &text)
{
    uint16_t track = trackForText(text);

    if (track == 0)
    {
        Serial.print("[speak] no audio for: ");
        Serial.println(text);
        return;
    }

    speakTrack(track);
}


void speakStop()
{
    speakPending = 0;
    speakFollow  = 0;

    if (speakerReady)
        dfPlayer.stop();
}


// =====================================================
// SERVICE  (call once per loop, never blocks)
// =====================================================
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
